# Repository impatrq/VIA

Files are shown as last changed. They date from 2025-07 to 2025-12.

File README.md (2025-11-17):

<div align="center">

# V.I.A. - IMPA TRQ

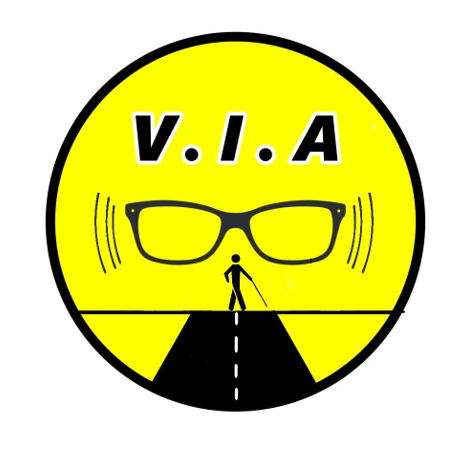
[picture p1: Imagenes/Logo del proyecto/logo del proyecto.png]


&nbsp;

| Página web | Email | Instagram |
|---|---|---|
|[VIA Web](https://linenlynx51926.github.io/VIA)|visioninteligenteasistida@gmail.com|[@vision_inteligente_asistida](https://www.instagram.com/vision_inteligente_asistida/)|

&nbsp;

</div>

## ¿Qué es VIA?

VIA es un prototipo de sistema de inspección y análisis visual para aeronaves, diseñado para optimizar procesos de verificación mediante sensores y captura de datos. Su objetivo principal es mejorar la detección temprana de fallas o anomalías a través de un análisis estructurado y automatizado.

## ¿Cómo funciona?
El sistema recibe la información proveniente de diferentes sensores y módulos de captura instalados en el equipo a inspeccionar. Mediante una secuencia guiada, VIA analiza parámetros críticos, registra lecturas y utiliza procesamiento visual para verificar el estado general.
Una vez procesados los datos, el sistema clasifica los resultados según su categoría o tipo de advertencia. Según el diagnóstico, VIA determina si el componente inspeccionado se encuentra dentro de tolerancias, si requiere seguimiento o si debe ser intervenido.
Las detecciones se organizan en cuatro categorías principales, permitiendo una interpretación clara y rápida del estado del sistema evaluado.

## ¿Quiénes somos?

Somos de la escuela tecnica IMPA, del curso 7° 2° Avionica

### GRANATA, Joaquin
* 📧 granatajoaquin@gmail.com

### RADAKOFF, Milovan
* 📧 miloradqw@gmail.com

### PAZ, Bautista
* 📧 bautistapaz504@gmail.com

### CARAM, Matias
* 📧 matias.rapero2007@gmail.com

### RAMIREZ, Selene
* 📧 seleneramirez474@gmail.com

<div align="center">

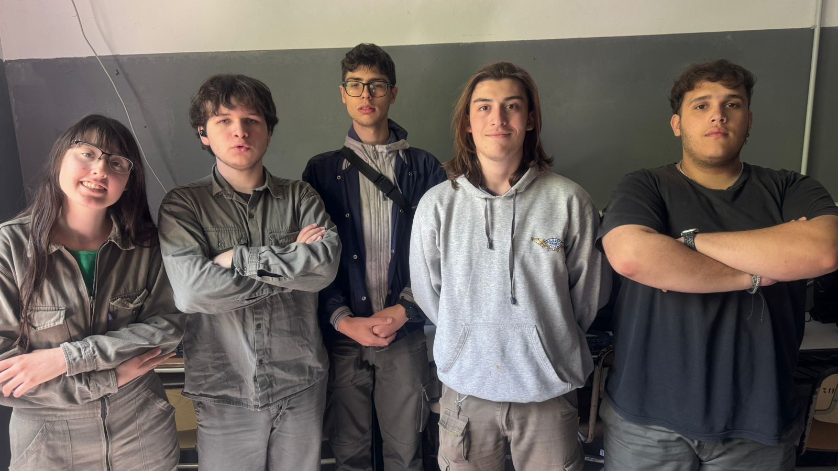
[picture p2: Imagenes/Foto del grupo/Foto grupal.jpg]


</div>

## ¿Cómo contactarnos?

* 📧 Email: visioninteligenteasistida@gmail.com

* 🌐 Página Web: https://linenlynx51926.github.io/VIA

* 🗞️ Linktr.ee: [VIA](https://linktr.ee/vision_inteligente_asistida)

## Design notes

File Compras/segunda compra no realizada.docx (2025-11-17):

11 | 1 | Sensor de proximidad | Para detectar la profundidad de los objetos en un area
12 | 1 | batería de litio | para alimetar los lentes
13 | 2 | Modulos con camaras ESP32 OV2640 de 2mp | se quemaron las 2 anteriores | https://tienda.starware.com.ar/producto/modulo-wifi-bt-camara-arduino-esp32-cam-ov2640-2mp/
14 | 1 | termocontraible | para aislar el circuito

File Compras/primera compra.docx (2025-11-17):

1 | 2 | Modulos con camaras ESP32 OV2640 de 2mp | Lo necesitamos para procesar las señales enviadas por los ecptores opticos. | https://tienda.starware.com.ar/producto/modulo-wifi-bt-camara-arduino-esp32-cam-ov2640-2mp/
2 | 1 | Placa SBC raspberry PI 5 model B 8GB RAM | Lo necesitamos para procesar, analizar y almacenar los datos que le proporcionamos. | https://tienda.starware.com.ar/producto/placa-sbc-raspberry-pi-5-model-b-8gb-ram/
3 | 1 | Sensor de proximidad DIY RCWL-0516 detector | Lo necesitamos para detectar objetos con los que se podria golpear el no vidente | https://tienda.starware.com.ar/producto/sensor-movimiento-proximidad-diy-rcwl-0516-detector-radar-doppler-microondas/
4 | 4 | Capacitores de 1μf | Para la conexión y funcionamiento del circuito de audio
5 | 4 | Capacitores ceramicos de 33μf | Para la conexión y funcionamiento del circuito de audio
6 | 4 | Resistencias de 270 ohms | Para la conexión y funcionamiento del circuito de audio
7 | 4 | Resistencias de 150 ohms | Para la conexión y funcionamiento del circuito de audio
8 | 1 | Pack de cables pin arduino macho a hembra | Es para conexiones varias
9 | 1 | Modulo amplificador audio starware PAM8403 5V | Es para transformar y amplificar la señal de audio que proviene del aparato | https://tienda.starware.com.ar/producto/modulo-amplificador-audio-starware-pam8403-5v-2ch-stereo-3w-con-volumen/
10 | 1 | Adaptador de jack a pines arduino | Lo vamos a usar para la conexión de tipo jack al circuito

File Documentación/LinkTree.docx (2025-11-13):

PARA CONOCER MAS DE ESTE GRAN PROYECTO,

¡¡TE INVITAMOS A VER NUESTROS OTROS MEDIOS!!

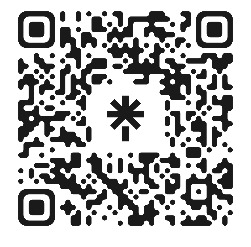
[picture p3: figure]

Visión Inteligente Artificial

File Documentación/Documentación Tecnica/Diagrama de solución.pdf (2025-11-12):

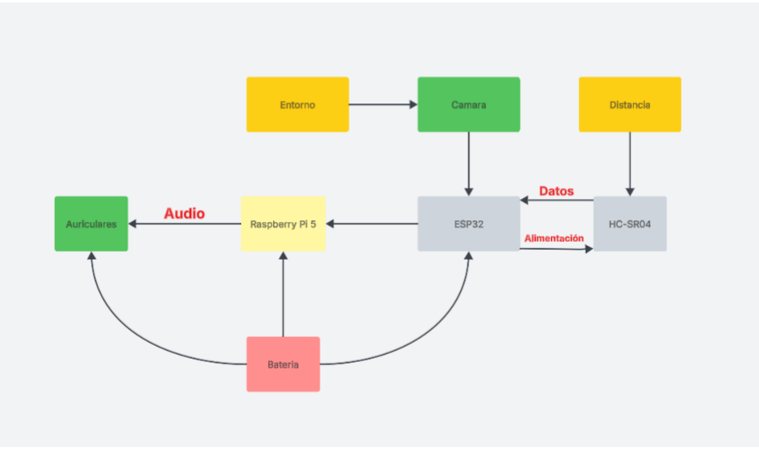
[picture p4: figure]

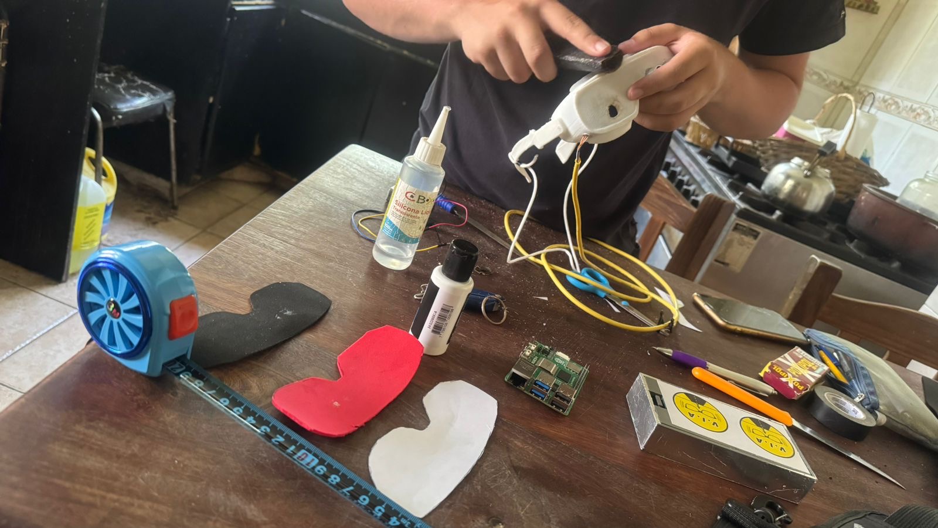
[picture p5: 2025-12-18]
Diseño de los lentes/74ddadd1-6766-4e61-b988-110f85c62abd.jpeg

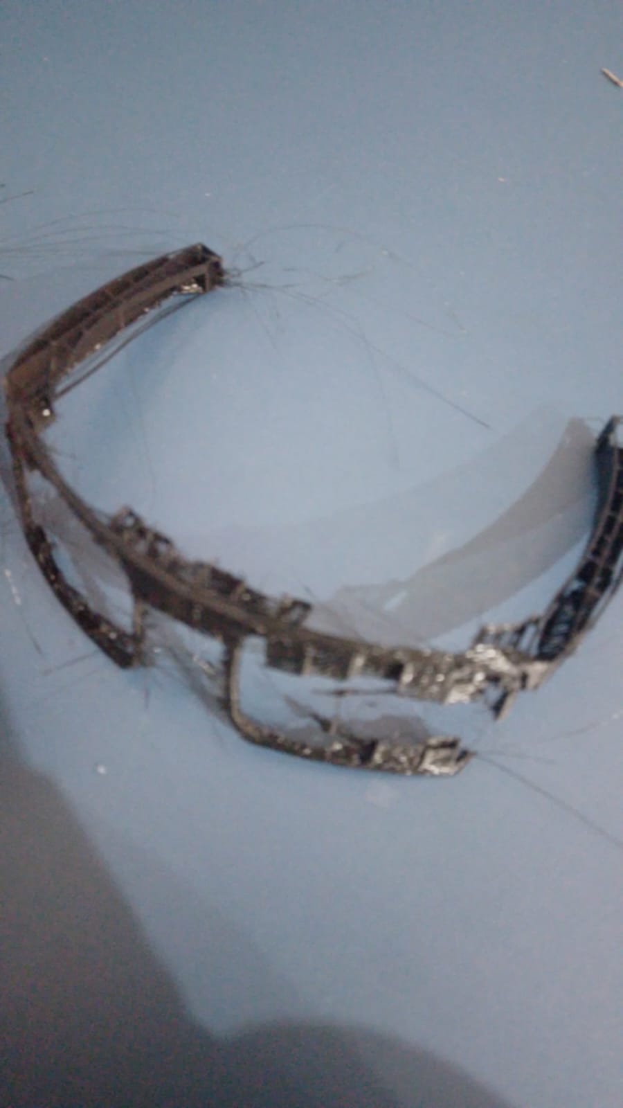
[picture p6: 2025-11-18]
Diseño de los lentes/segunda impresion de lentes.jpg

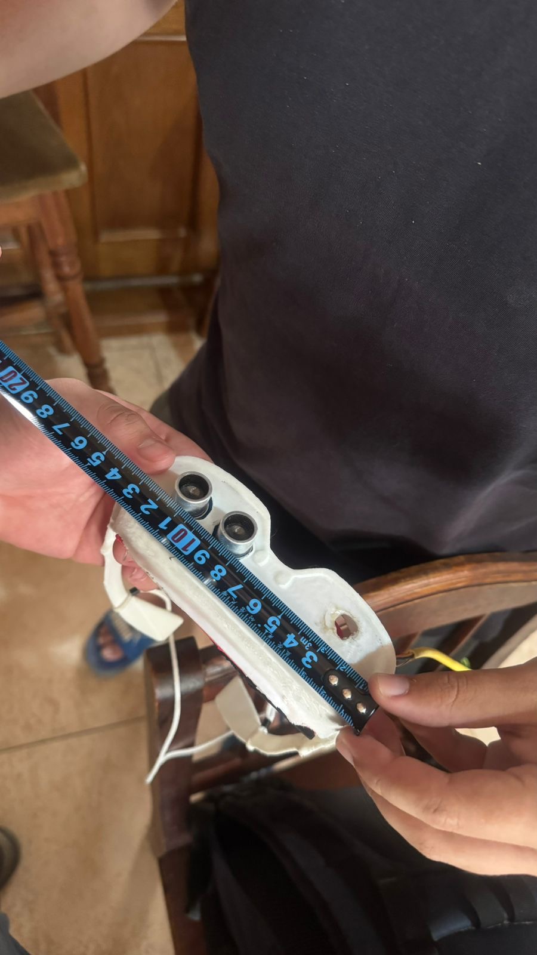
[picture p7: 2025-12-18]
Diseño de los lentes/55b00a65-91ff-49be-b2be-f18906fa94af.jpeg

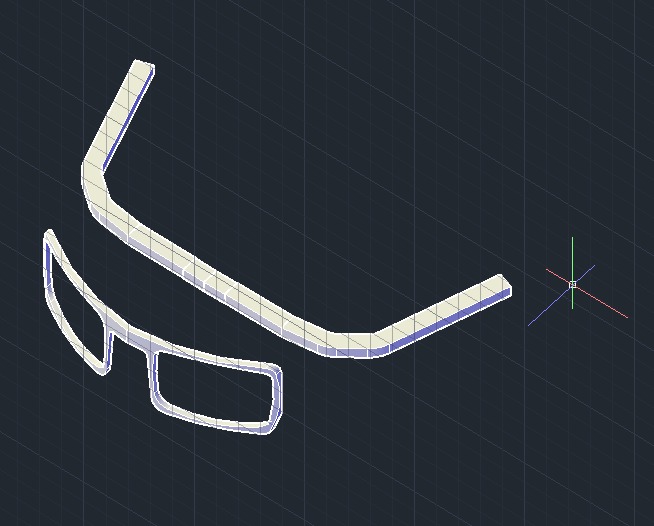
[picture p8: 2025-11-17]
Diseño de los lentes/cuarto diseño de lentes.jpg

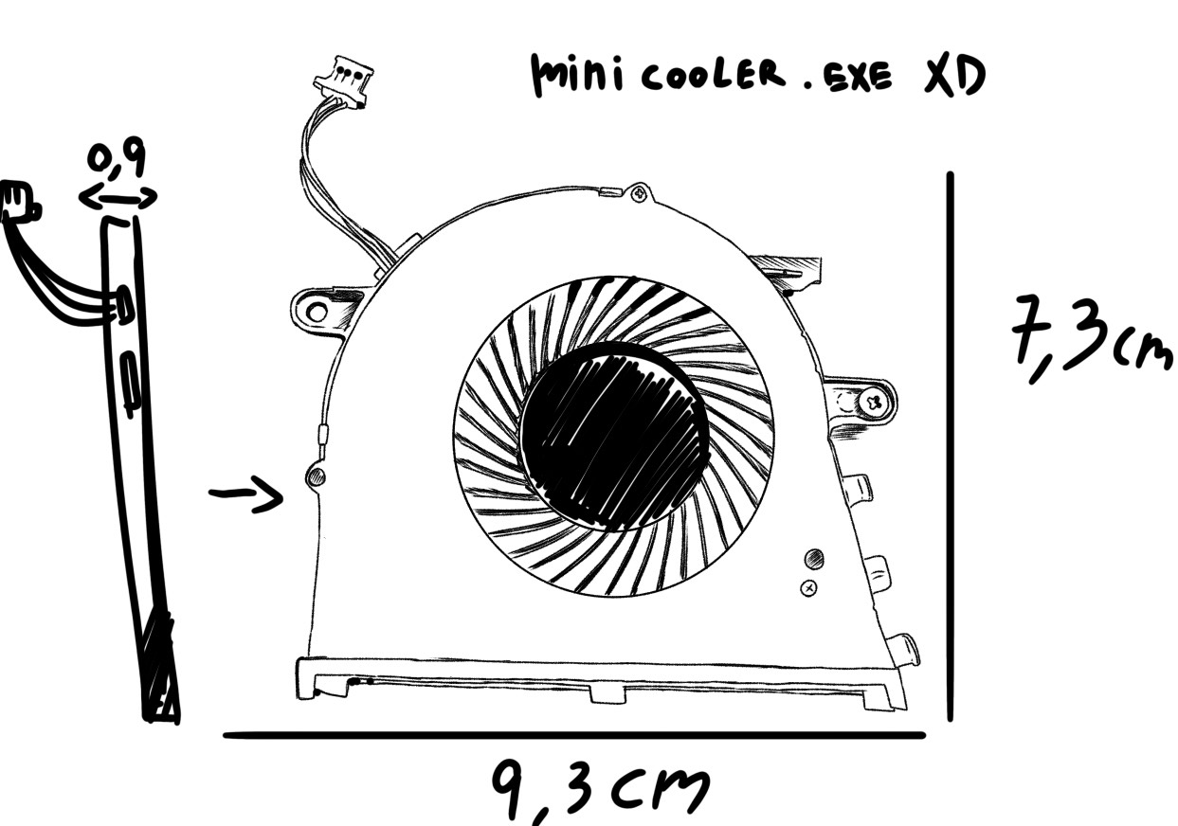
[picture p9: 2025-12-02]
Diseño de los lentes/image.png

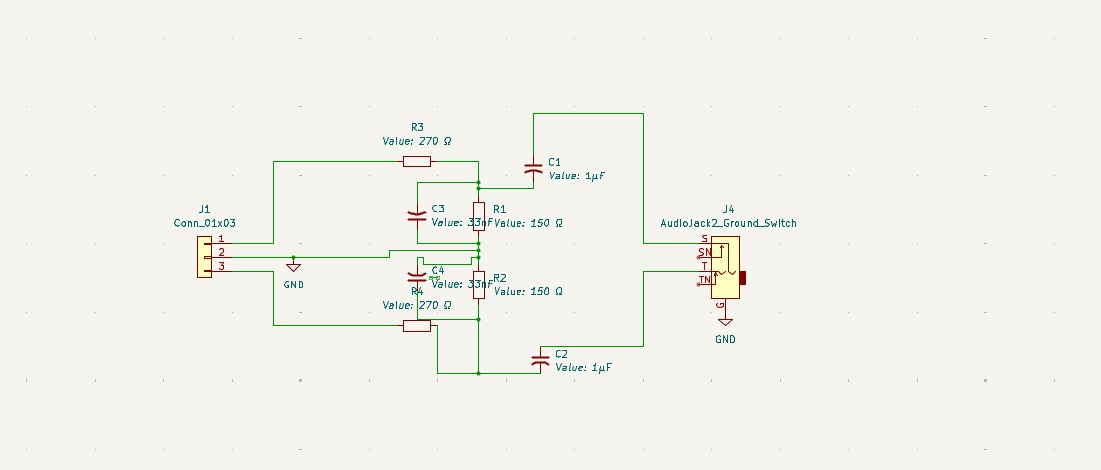
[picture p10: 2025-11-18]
circuito de audio/diseño de circuito.jpg

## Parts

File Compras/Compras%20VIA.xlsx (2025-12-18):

Planilla de compras Proyectos de 7mo Aviónica
Nombre del Proyecto |  | VIA |  | Alumnos Responsables: |  |  | AVIÓNICA
 |  |  |  | Milovan Radakoff | radakoff.milovan@gmail.com
 |  |  |  | Matias Caram | matias.rapero2007@gmail.com
Item | Cant. | Nombre del producto | Detalle del pedido | Link: | Precio por unidad | Sub Total | Fecha de solicitud | Tutores |  | Jefe de Área |  | Cooperadora
 |  |  |  |  |  |  |  | Aprobado | Fecha de aprobación | Aprobado | Fecha de aprobación | Estado | Fecha de entrega
1 | 2 | Modulos con camaras ESP32 OV2640 de 2mp | Lo necesitamos para procesar las señales enviadas por los ecptores opticos. | https://tienda.starware.com.ar/producto/modulo-wifi-bt-camara-arduino-esp32-cam-ov2640-2mp/ | $14739.00 | $29478.00 | #REF! | VERDADERO | #REF! | VERDADERO | #REF! | Presupuestando
2 | 1 | Placa SBC raspberry PI 5 model B 8GB RAM | Lo necesitamos para procesar, analizar y almacenar los datos que le proporcionamos. | https://tienda.starware.com.ar/producto/placa-sbc-raspberry-pi-5-model-b-8gb-ram/ | $125009.00 | $125009.00 | #REF! | VERDADERO | #REF! | VERDADERO | #REF! | Presupuestando
3 | 1 | Sensor de proximidad DIY RCWL-0516 detector | Lo necesitamos para detectar objetos con los que se podria golpear el no vidente | https://tienda.starware.com.ar/producto/sensor-movimiento-proximidad-diy-rcwl-0516-detector-radar-doppler-microondas/ | $5189.00 | $5189.00 | #REF! | VERDADERO | #REF! | VERDADERO | #REF! | Presupuestando
4 | 4 | Capacitores de 1μf | Para la conexión y funcionamiento del circuito de audio |  | $2618.00 | $10472.00 | #REF! | VERDADERO | #REF! | VERDADERO | #REF! | Presupuestando
5 | 4 | Capacitores ceramicos de 33μf | Para la conexión y funcionamiento del circuito de audio |  | $2618.00 | $10472.00 | #REF! | VERDADERO | #REF! | VERDADERO | #REF! | Presupuestando
6 | 4 | Resistencias de 270 ohms | Para la conexión y funcionamiento del circuito de audio |  | $1202.03 | $4808.12 | #REF! | VERDADERO | #REF! | VERDADERO | #REF! | Presupuestando
7 | 4 | Resistencias de 150 ohms | Para la conexión y funcionamiento del circuito de audio |  | $4584.00 | $18336.00 | #REF! | VERDADERO | #REF! | VERDADERO | #REF! | Presupuestando
8 | 1 | Pack de cables pin arduino macho a hembra | Es para conexiones varias |  | $3000.00 | $3000.00 | #REF! | VERDADERO | #REF! | VERDADERO | #REF! | Presupuestando
9 | 1 | Modulo amplificador audio starware PAM8403 5V | Es para transformar y amplificar la señal de audio que proviene del aparato | https://tienda.starware.com.ar/producto/modulo-amplificador-audio-starware-pam8403-5v-2ch-stereo-3w-con-volumen/ | $2279.00 | $2279.00 | #REF! | VERDADERO | #REF! | VERDADERO | #REF! | Presupuestando
10 | 1 | Adaptador de jack a pines arduino | Lo vamos a usar para la conexión de tipo jack al circuito |  | $5300.00 | $5300.00 | #REF! | VERDADERO | #REF! | VERDADERO | #REF! | Presupuestando
11 | 1 | Sensor de proximidad | Para detectar la profundidad de los objetos en un area |  | $16000.00 | $16000.00 | #REF! | VERDADERO | #REF! | VERDADERO | #REF! | Presupuestando
12 | 1 | batería de litio | para alimetar los lentes |  | $7700.00 | $7700.00 | #REF! | VERDADERO | #REF! | VERDADERO | #REF! | Presupuestando
13 | 2 | Modulos con camaras ESP32 OV2640 de 2mp | se quemaron las 2 anteriores | https://tienda.starware.com.ar/producto/modulo-wifi-bt-camara-arduino-esp32-cam-ov2640-2mp/ |  | $0.00 | #REF! |  |  |  |  | Presupuestando
14 | 1 | termocontraible | para aislar el circuito |  |  | $0.00 | #REF! |  |  |  |  | Presupuestando
15 | 1 | Auriculares óseos bluethoot | Para transmitir el mensaje al usuario sin obstruir su vía auditiva |  | $18000.00 | $18000.00 | #REF! |  |  |  |  | Presupuestando
16 |  |  |  |  |  | $0.00 |  |  |  |  |  | Presupuestando
17 |  |  |  |  |  | $0.00 |  |  |  |  |  | Presupuestando
18 |  |  |  |  |  | $0.00 |  |  |  |  |  | Presupuestando
19 |  |  |  |  |  | $0.00 |  |  |  |  |  | Presupuestando
20 |  |  |  |  |  | $0.00 |  |  |  |  |  | Presupuestando
21 |  |  |  |  |  | $0.00 |  |  |  |  |  | Presupuestando
22 |  |  |  |  |  | $0.00 |  |  |  |  |  | Presupuestando
23 |  |  |  |  |  | $0.00 |  |  |  |  |  | Presupuestando
24 |  |  |  |  |  | $0.00 |  |  |  |  |  | Presupuestando
25 |  |  |  |  |  | $0.00 |  |  |  |  |  | Presupuestando
26 |  |  |  |  |  | $0.00 |  |  |  |  |  | Presupuestando
27 |  |  |  |  |  | $0.00 |  |  |  |  |  | Presupuestando
28 |  |  |  |  |  | $0.00 |  |  |  |  |  | Presupuestando
29 |  |  |  |  |  | $0.00 |  |  |  |  |  | Presupuestando
30 |  |  |  |  |  | $0.00 |  |  |  |  |  | Presupuestando
 |  |  |  |  | Total: | $256043.12 |  | Gastado: | $0.00

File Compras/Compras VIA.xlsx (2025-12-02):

Planilla de compras Proyectos de 7mo Aviónica
Nombre del Proyecto |  | VIA |  | Alumnos Responsables: |  |  | AVIÓNICA
 |  |  |  | Milovan Radakoff | radakoff.milovan@gmail.com
 |  |  |  | Matias Caram | matias.rapero2007@gmail.com
Item | Cant. | Nombre del producto | Detalle del pedido | Link: | Precio por unidad | Sub Total | Fecha de solicitud | Tutores |  | Jefe de Área |  | Cooperadora
 |  |  |  |  |  |  |  | Aprobado | Fecha de aprobación | Aprobado | Fecha de aprobación | Estado | Fecha de entrega
1 | 2 | Modulos con camaras ESP32 OV2640 de 2mp | Lo necesitamos para procesar las señales enviadas por los ecptores opticos. | https://tienda.starware.com.ar/producto/modulo-wifi-bt-camara-arduino-esp32-cam-ov2640-2mp/ | $14739.00 | $29478.00 | 2025-06-19 14:22 | VERDADERO | 2025-06-24 14:38 | VERDADERO | 2025-07-01 16:15 | Presupuestando
2 | 1 | Placa SBC raspberry PI 5 model B 8GB RAM | Lo necesitamos para procesar, analizar y almacenar los datos que le proporcionamos. | https://tienda.starware.com.ar/producto/placa-sbc-raspberry-pi-5-model-b-8gb-ram/ | $125009.00 | $125009.00 | 2025-06-19 14:22 | VERDADERO | 2025-06-24 14:38 | VERDADERO | 2025-07-01 16:15 | Presupuestando
3 | 1 | Sensor de proximidad DIY RCWL-0516 detector | Lo necesitamos para detectar objetos con los que se podria golpear el no vidente | https://tienda.starware.com.ar/producto/sensor-movimiento-proximidad-diy-rcwl-0516-detector-radar-doppler-microondas/ | $5189.00 | $5189.00 | 2025-06-19 14:22 | VERDADERO | 2025-06-24 14:38 | VERDADERO | 2025-07-01 16:15 | Presupuestando
4 | 4 | Capacitores de 1μf | Para la conexión y funcionamiento del circuito de audio |  | $2618.00 | $10472.00 | 2025-09-09 14:00 | VERDADERO | 2025-06-24 14:38 | VERDADERO | 2025-07-01 16:15 | Presupuestando
5 | 4 | Capacitores ceramicos de 33μf | Para la conexión y funcionamiento del circuito de audio |  | $2618.00 | $10472.00 | 2025-09-09 14:00 | VERDADERO | 2025-06-24 14:38 | VERDADERO | 2025-07-01 16:15 | Presupuestando
6 | 4 | Resistencias de 270 ohms | Para la conexión y funcionamiento del circuito de audio |  | $1202.03 | $4808.12 | 2025-09-09 14:00 | VERDADERO | 2025-06-24 14:38 | VERDADERO | 2025-07-01 16:15 | Presupuestando
7 | 4 | Resistencias de 150 ohms | Para la conexión y funcionamiento del circuito de audio |  | $4584.00 | $18336.00 | 2025-09-09 14:00 | VERDADERO | 2025-06-24 14:38 | VERDADERO | 2025-07-01 16:15 | Presupuestando
8 | 1 | Pack de cables pin arduino macho a hembra | Es para conexiones varias |  | $3000.00 | $3000.00 | 2025-09-09 14:00 | VERDADERO | 2025-06-24 14:38 | VERDADERO | 2025-07-01 16:15 | Presupuestando
9 | 1 | Modulo amplificador audio starware PAM8403 5V | Es para transformar y amplificar la señal de audio que proviene del aparato | https://tienda.starware.com.ar/producto/modulo-amplificador-audio-starware-pam8403-5v-2ch-stereo-3w-con-volumen/ | $2279.00 | $2279.00 | 2025-09-09 14:00 | VERDADERO | 2025-06-24 14:38 | VERDADERO | 2025-07-01 16:15 | Presupuestando
10 | 1 | Adaptador de jack a pines arduino | Lo vamos a usar para la conexión de tipo jack al circuito |  | $5300.00 | $5300.00 | 2025-09-09 14:00 | VERDADERO | 2025-06-24 14:38 | VERDADERO | 2025-07-01 16:25 | Presupuestando
11 | 1 | Sensor de proximidad | Para detectar la profundidad de los objetos en un area |  | $16000.00 | $16000.00 | 2025-09-09 14:00 | VERDADERO | 2025-09-09 14:26 | VERDADERO | 2025-09-09 14:26 | Presupuestando
12 | 1 | batería de litio | para alimetar los lentes |  | $7700.00 | $7700.00 | 2025-10-21 10:05 | VERDADERO | 2025-09-09 14:26 | VERDADERO | 2025-09-09 14:26 | Presupuestando
13 | 2 | Modulos con camaras ESP32 OV2640 de 2mp | se quemaron las 2 anteriores | https://tienda.starware.com.ar/producto/modulo-wifi-bt-camara-arduino-esp32-cam-ov2640-2mp/ |  | $0.00 | 2025-09-16 16:21 |  |  |  |  | Presupuestando
14 | 1 | termocontraible | para aislar el circuito |  |  | $0.00 | 2025-10-21 10:05 |  |  |  |  | Presupuestando
15 | 1 | Auriculares óseos bluethoot | Para transmitir el mensaje al usuario sin obstruir su vía auditiva |  | $18000.00 | $18000.00 |  |  |  |  |  | Presupuestando
16 |  |  |  |  |  | $0.00 |  |  |  |  |  | Presupuestando
17 |  |  |  |  |  | $0.00 |  |  |  |  |  | Presupuestando
18 |  |  |  |  |  | $0.00 |  |  |  |  |  | Presupuestando
19 |  |  |  |  |  | $0.00 |  |  |  |  |  | Presupuestando
20 |  |  |  |  |  | $0.00 |  |  |  |  |  | Presupuestando
21 |  |  |  |  |  | $0.00 |  |  |  |  |  | Presupuestando
22 |  |  |  |  |  | $0.00 |  |  |  |  |  | Presupuestando
23 |  |  |  |  |  | $0.00 |  |  |  |  |  | Presupuestando
24 |  |  |  |  |  | $0.00 |  |  |  |  |  | Presupuestando
25 |  |  |  |  |  | $0.00 |  |  |  |  |  | Presupuestando
26 |  |  |  |  |  | $0.00 |  |  |  |  |  | Presupuestando
27 |  |  |  |  |  | $0.00 |  |  |  |  |  | Presupuestando
28 |  |  |  |  |  | $0.00 |  |  |  |  |  | Presupuestando
29 |  |  |  |  |  | $0.00 |  |  |  |  |  | Presupuestando
30 |  |  |  |  |  | $0.00 |  |  |  |  |  | Presupuestando
 |  |  |  |  | Total: | $256043.12 |  | Gastado: | $0.00

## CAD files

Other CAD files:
Diseño de los lentes/tercer diseño de lentes.dwg
Diseño de los lentes/segundo diseño de lentes.dwg
Diseño de los lentes/primer diseño e idea de lentes.dwg

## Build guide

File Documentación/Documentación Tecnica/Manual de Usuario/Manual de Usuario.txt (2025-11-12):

\documentclass[12pt,a4paper]{article}

% Paquetes
\usepackage[utf8]{inputenc}
\usepackage[spanish]{babel}
\usepackage{graphicx}
\usepackage{hyperref}
\usepackage{geometry}
\usepackage{titlesec}
\usepackage{xcolor}
\usepackage{fancyhdr}
\usepackage{enumitem}

\geometry{margin=2.5cm}

\pagestyle{fancy}
\fancyhf{}
\fancyhead[L]{Proyecto V.I.A.}
\fancyhead[R]{Manual de Usuario}
\fancyfoot[C]{\thepage}

\titleformat{\section}{\Large\bfseries}{\thesection.}{0.5em}{}
\titleformat{\subsection}{\large\bfseries}{\thesubsection.}{0.5em}{}

\title{\textbf{Manual de Usuario}\\Proyecto V.I.A.}
\author{Equipo de Desarrollo V.I.A.}
\date{}

\begin{document}

\maketitle
\thispagestyle{empty}
\vspace{2cm}

\begin{center}
\includegraphics[width=0.55\textwidth]{VIA-Logo.png}
\end{center}

\newpage
\tableofcontents
\newpage

\section{Introducción}
El presente documento corresponde al \textbf{Manual de Usuario} del sistema \textbf{V.I.A. (Visión Inteligente Asistida)}.  
Su propósito es ofrecer una guía clara y sencilla para poner en funcionamiento el dispositivo, sin necesidad de conocimientos avanzados en informática o programación.

El sistema \textbf{V.I.A.} fue desarrollado como una herramienta de apoyo para personas con discapacidad visual o movilidad reducida. Combina sensores ópticos, ultrasónicos y procesamiento local en una \textbf{Raspberry Pi 5} para detectar obstáculos cercanos y emitir alertas sonoras al usuario en tiempo real.

\section{Componentes principales}
\subsection{Lentes inteligentes}
Los lentes alojan los sensores del sistema:
\begin{itemize}
    \item \textbf{Cámara ESP32-CAM:} capta imágenes del entorno.
    \item \textbf{Sensor ultrasónico HC-SR04:} mide la distancia a los objetos cercanos.
\end{itemize}
Los módulos están integrados en el armazón y conectados mediante un cable a la unidad central.

\subsection{Auriculares Bluetooth}
Los auriculares son el medio por el cual el usuario recibe las alertas.  
El sistema se conecta automáticamente al encenderse, siempre que los auriculares estén emparejados una vez.

\subsection{Unidad de procesamiento (Raspberry Pi 5)}
Es el “cerebro” del sistema. Contiene el software de detección, comunicación y control.  
Al iniciar, se encarga de conectar todos los componentes y mostrar una interfaz visual en pantalla o en otro dispositivo.

\section{Requisitos previos}
Antes de usar el sistema, asegúrese de:
\begin{itemize}
    \item Contar con todos los módulos correctamente conectados (lentes, cámara, sensor y auriculares).
    \item Tener una fuente de alimentación estable (5V / 3A).
    \item Haber realizado el emparejamiento inicial de los auriculares Bluetooth (solo la primera vez).
\end{itemize}

\section{Encendido y funcionamiento}
\subsection{Inicio automático}
Al conectar la Raspberry Pi:
\begin{enumerate}
    \item Se inicia automáticamente el sistema V.I.A.  
    \item En pantalla (o en un dispositivo conectado) aparecerá la interfaz principal con opciones como:
    \begin{itemize}
        \item \textbf{Iniciar detección}
        \item \textbf{Ver cámara}
        \item \textbf{Estado del sistema}
        \item \textbf{Apagar o reiniciar}
    \end{itemize}
    \item Los auriculares emitirán un sonido de confirmación al estar listos.
\end{enumerate}

\subsection{Modo detección}
Al presionar el botón \textbf{“Iniciar detección”} en la interfaz:
\begin{itemize}
    \item El sistema comienza a analizar el entorno con la cámara y el sensor ultrasónico.  
    \item Si se detecta un obstáculo cercano, los auriculares emiten un tono o mensaje de advertencia.  
    \item El nivel de alerta varía según la distancia detectada.
\end{itemize}

\subsection{Modo monitoreo (opcional)}
Si el sistema está conectado a una pantalla o red local, se puede acceder desde un navegador en:
\begin{center}
\textbf{http://via.local}
\end{center}
Allí es posible visualizar las imágenes y el estado de los sensores en tiempo real.

\section{Solución de problemas}
\begin{itemize}
    \item \textbf{No se escuchan las alertas:}  
    Verifique que los auriculares estén encendidos y dentro del alcance. Si es necesario, repita el emparejamiento desde la interfaz.

    \item \textbf{El sistema no inicia:}  
    Compruebe la fuente de alimentación y los cables de conexión. Si la pantalla muestra un error, reinicie el dispositivo.

    \item \textbf{El sensor no responde:}  
    Revise que el sensor ultrasónico esté limpio y firmemente conectado. Evite ambientes húmedos o con polvo.

    \item \textbf{La cámara no muestra imagen:}  
    Verifique que la cámara esté correctamente orientada y que no haya objetos cubriendo la lente.
\end{itemize}

\section{Mantenimiento básico}
\begin{itemize}
    \item Limpie la cámara y el sensor con un paño seco.  
    \item Guarde los lentes en un lugar seco y seguro.  
    \item Actualice el software del sistema cuando la interfaz lo indique.  
    \item No conecte ni desconecte módulos con el sistema encendido.
\end{itemize}

\section{Seguridad}
\begin{itemize}
    \item No exponga el sistema al agua o altas temperaturas.  
    \item Mantenga los cables y conexiones en buen estado.  
    \item Utilice solo cargadores certificados de 5V / 3A.  
    \item No manipule la Raspberry Pi sin desconectarla previamente.
\end{itemize}

\section{Datos técnicos}
\begin{itemize}
    \item \textbf{Procesador:} Raspberry Pi 5 (Quad-Core Cortex-A76)
    \item \textbf{Cámara:} ESP32-CAM OV2640
    \item \textbf{Sensor:} HC-SR04
    \item \textbf{Conectividad:} WiFi 2.4 GHz, Bluetooth 5.0
    \item \textbf{Alimentación:} 5V / 3A
    \item \textbf{Software:} Python 3.11, OpenCV, Flask
\end{itemize}

\section{Soporte técnico}
En caso de inconvenientes, comuníquese con el equipo del Proyecto V.I.A. mediante los canales institucionales o correo electrónico del grupo de desarrollo.

\vfill
\begin{center}
\textit{“VIA – Con nosotros, cada paso es un paso seguro.”}
\end{center}

\end{document}

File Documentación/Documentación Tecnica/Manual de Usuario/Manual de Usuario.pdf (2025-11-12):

# Manual de Usuario

Proyecto V.I.A.

Equipo de Desarrollo V.I.A.

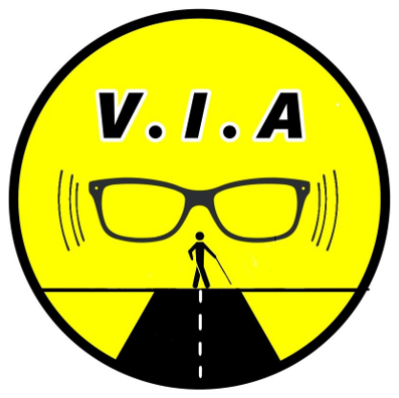
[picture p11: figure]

Proyecto V.I.A. | Manual de Usuario

## Índice

1. Introducción | 3
2. Componentes principales | 3
3. Requisitos previos | 3
4. Encendido y funcionamiento | 4
5. Solución de problemas | 4
6. Mantenimiento básico | 5
7. Seguridad | 5
8. Datos técnicos | 5
9. Soporte técnico | 5

## 1. Introducción

El presente documento corresponde al Manual de Usuario del sistema V.I.A. (Visión Inteligente Asistida). Su propósito es ofrecer una guía clara y sencilla para poner en funcionamiento el dispositivo, sin necesidad de conocimientos avanzados en informática o programación.
El sistema V.I.A. fue desarrollado como una herramienta de apoyo para personas con discapacidad visual o movilidad reducida. Combina sensores ópticos, ultrasónicos y procesamiento local en una Raspberry Pi 5 para detectar obstáculos cercanos y emitir alertas sonoras al usuario en tiempo real.

## 2. Componentes principales

### 2.1. Lentes inteligentes

Los lentes alojan los sensores del sistema:

Cámara ESP32-CAM: capta imágenes del entorno.

Sensor ultrasónico HC-SR04: mide la distancia a los objetos cercanos.

Los módulos están integrados en el armazón y conectados mediante un cable a la unidad central.

### 2.2. Auriculares Bluetooth

Los auriculares son el medio por el cual el usuario recibe las alertas. El sistema se conecta automáticamente al encenderse, siempre que los auriculares estén emparejados una vez.

### 2.3. Unidad de procesamiento (Raspberry Pi 5)

Es el “cerebro” del sistema. Contiene el software de detección, comunicación y control. Al iniciar, se encarga de conectar todos los componentes y mostrar una interfaz visual en pantalla o en otro dispositivo.

## 3. Requisitos previos

Antes de usar el sistema, asegúrese de:

Contar con todos los módulos correctamente conectados (lentes, cámara, sensor y auriculares).

Tener una fuente de alimentación estable (5V / 3A).

Haber realizado el emparejamiento inicial de los auriculares Bluetooth (solo la primera vez).

## 4. Encendido y funcionamiento

### 4.1. Inicio automático

Al conectar la Raspberry Pi:

1. Se inicia automáticamente el sistema V.I.A.
2. En pantalla (o en un dispositivo conectado) aparecerá la interfaz principal con opciones como:

Iniciar detección

Ver cámara

Estado del sistema

Apagar o reiniciar

3. Los auriculares emitirán un sonido de confirmación al estar listos.

### 4.2. Modo detección

Al presionar el botón “Iniciar detección” en la interfaz:

El sistema comienza a analizar el entorno con la cámara y el sensor ultrasónico.

Si se detecta un obstáculo cercano, los auriculares emiten un tono o mensaje de advertencia.

El nivel de alerta varía según la distancia detectada.

### 4.3. Modo monitoreo (opcional)

Si el sistema está conectado a una pantalla o red local, se puede acceder desde un navegador en:

http://via.local

Allí es posible visualizar las imágenes y el estado de los sensores en tiempo real.

## 5. Solución de problemas

No se escuchan las alertas: Verifique que los auriculares estén encendidos y dentro del alcance. Si es necesario, repita el emparejamiento desde la interfaz.

El sistema no inicia: Compruebe la fuente de alimentación y los cables de conexión. Si la pantalla muestra un error, reinicie el dispositivo.

El sensor no responde: Revise que el sensor ultrasónico esté limpio y firmemente conectado. Evite ambientes húmedos o con polvo.

La cámara no muestra imagen: Verifique que la cámara esté correctamente orientada y que no haya objetos cubriendo la lente.

## 6. Mantenimiento básico

Limpie la cámara y el sensor con un paño seco.

Guarde los lentes en un lugar seco y seguro.

Actualice el software del sistema cuando la interfaz lo indique.

No conecte ni desconecte módulos con el sistema encendido.

## 7. Seguridad

No exponga el sistema al agua o altas temperaturas.

Mantenga los cables y conexiones en buen estado.

Utilice solo cargadores certificados de 5V / 3A.

No manipule la Raspberry Pi sin desconectarla previamente.

## 8. Datos técnicos

Procesador: Raspberry Pi 5 (Quad-Core Cortex-A76)

Cámara: ESP32-CAM OV2640

Sensor: HC-SR04

Conectividad: WiFi 2.4 GHz, Bluetooth 5.0

Alimentación: 5V / 3A

Software: Python 3.11, OpenCV, Flask

## 9. Soporte técnico

En caso de inconvenientes, comuníquese con el equipo del Proyecto V.I.A. mediante los canales institucionales o correo electrónico del grupo de desarrollo.

“VIA – Con nosotros, cada paso es un paso seguro.”

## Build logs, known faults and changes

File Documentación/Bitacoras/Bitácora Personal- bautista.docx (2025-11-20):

# Bitácora Personal

Bautista Paz 7° 2° aviónica com B proyecto V.I.A

# 16/4 (miercoles 16 de abril)

Comienzo a hacer el logo del proyecto V.I.A

18/4 (viernes 18 de abril)

Después de haber terminado con el logo, empecé un curso de programación para así poder practicar y mejorar.

23/4 (miércoles 23 de abril)

Después de ir viendo el curso y de que me sugirieran ir practicando, pensé en hacer un bot de respuesta para ir poniendo a prueba si aprendí algo.

29/4 (martes 29 de abril)

Después de ver algunos cursos y tutoriales faltaba saber como iba a programar todo y primero pensé hacerlo en visual studio code y descargando por así decirlo el lenguaje de phyton para poder usarlo en VSC. Y de ahí empezar a practicar para programa un chatbot simple.

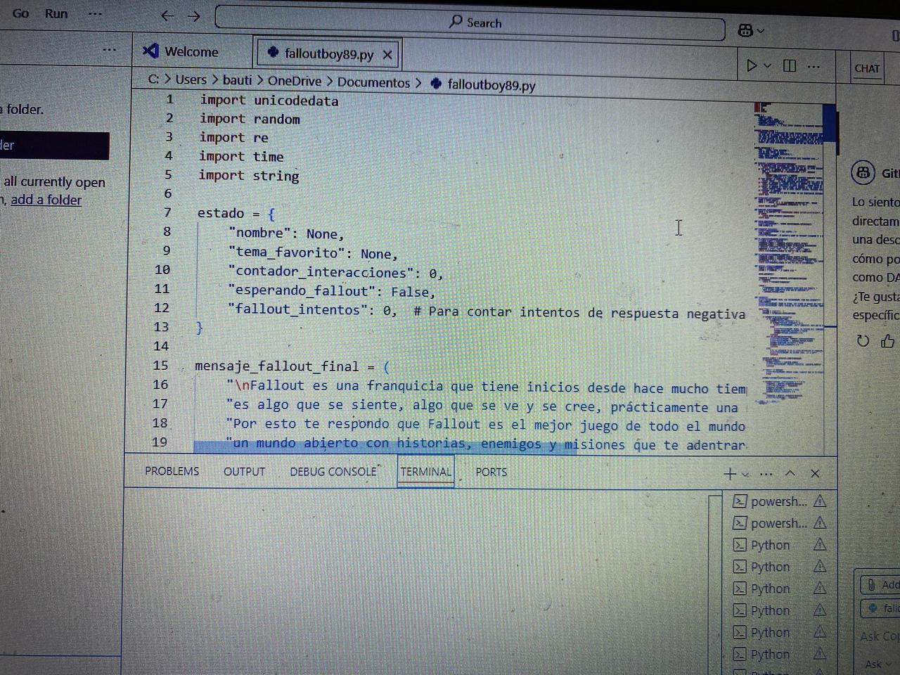
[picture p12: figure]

(ahora que lo pienso tuve que haber sacado más fotos del comienzo para que se vea mejor el progreso)

6/5 (martes 5 de mayo)

Después de ver el curso de programación y ya haber avanzado mas con el chatbot siendo que ahora aparte de hablar de mi temática favorita también hice que pudiera cambiar su forma de ser y hablar conforme la persona que habla para que así no sea repetitivo en cuanto al tema que hablará y como lo hará

7/5 (miércoles 7 de mayo)

Al dia siguiente pensé en dejarlo por ahora para seguirlo mas a futuro y pensar hacer un bot de respuesta que responda todo en base a datos ya sea de Wikipedia sin necesidad de depender de una red wi fi y así sea una biblioteca andante sin necesidad de pesar hasta 1T de espacio. Ahora lo que tocaba era programar el sensor de proximidad.

13/5 (martes 13 de mayo)

Empezando a programar las bases del sensor de proximidad pensando en un sistema que ayude a las personas que padezcan de ceguera el poder moverse por las calles sin problemas y para esto terminé simulando en wokwi.

16/5 (viernes 16 de mayo)

Hubo problemas al tratar de simular el sensor de proximidad con wokwi, asi que se cambió a arduino ya que no había dificultades al programar y simular (pd: me recomendaron hacerlo en tinkercad como alternativa)

#define TRIG_PIN 9

#define ECHO_PIN 8

#define BUZZER_A 7

#define BUZZER_B 6

#define BUZZER_C 5

void setup() {

Serial.begin(9600);

pinMode(TRIG_PIN, OUTPUT);

pinMode(ECHO_PIN, INPUT);

pinMode(BUZZER_A, OUTPUT);

pinMode(BUZZER_B, OUTPUT);

pinMode(BUZZER_C, OUTPUT);

}

void loop() {

digitalWrite(TRIG_PIN, LOW);

delayMicroseconds(2);

digitalWrite(TRIG_PIN, HIGH);

delayMicroseconds(10);

digitalWrite(TRIG_PIN, LOW);

long duracion = pulseIn(ECHO_PIN, HIGH);

float distancia = duracion * 0.0343 / 2;

// Apaga todos los buzzers antes de activar el correcto

digitalWrite(BUZZER_A, LOW);

digitalWrite(BUZZER_B, LOW);

digitalWrite(BUZZER_C, LOW);

if (distancia <= 200) {

Serial.println("Objeto adelante");

digitalWrite(BUZZER_A, HIGH);

}

else if (distancia > 200 && distancia <= 350) {

Serial.println("Objeto acercándose");

digitalWrite(BUZZER_B, HIGH);

}

else {

Serial.println("Camino despejado");

digitalWrite(BUZZER_C, HIGH);

}

delay(1000);

28/5 (miércoles 28 de mayo)

Se tuvo la reunión con la ASAC una asociación que ayuda a las personas con ceguera y por eso mismo gracias a ellos se aprendio mejor y se recibió mayor información de estos.

Martes 3 de junio

Después de la compra de algunos componentes me puse a instalar las aplicaciones para poder así programár todo para los sensores de movimiento. Para esto busque primero formas fáciles de probarlo y encontré termius, una aplicación que me ayudaba a probar el código de los sensores de proximidad sin problema.

Miércoles 4 de junio

Como no había buzzers en su momento tuve que usar leds de colores para simular las distancias (rojo = objeto cerca; verde = objeto lejos; amarillo objeto aproximándose). Y esto llevaba a que tenga que cambiar el código a uno de leds.

#define TRIG_PIN 9

#define ECHO_PIN 8

#define BUZZER_A 7

#define BUZZER_B 6

#define BUZZER_C 5

void setup() {

Serial.begin(9600);

pinMode(TRIG_PIN, OUTPUT);

pinMode(ECHO_PIN, INPUT);

pinMode(BUZZER_A, OUTPUT);

pinMode(BUZZER_B, OUTPUT);

pinMode(BUZZER_C, OUTPUT);

}

void loop() {

digitalWrite(TRIG_PIN, LOW);

delayMicroseconds(2);

digitalWrite(TRIG_PIN, HIGH);

delayMicroseconds(10);

digitalWrite(TRIG_PIN, LOW);

long duracion = pulseIn(ECHO_PIN, HIGH, 30000); // timeout opcional de 30 ms

if (duracion == 0) {

Serial.println("Sin lectura (fuera del rango)");

digitalWrite(BUZZER_A, LOW);

digitalWrite(BUZZER_B, LOW);

digitalWrite(BUZZER_C, LOW);

} else {

float distancia = duracion * 0.0343 / 2;

Serial.print("Distancia: ");

Serial.print(distancia);

Serial.println(" cm");

digitalWrite(BUZZER_A, LOW);

digitalWrite(BUZZER_B, LOW);

digitalWrite(BUZZER_C, LOW);

if (distancia <= 200) {

Serial.println("Objeto adelante");

digitalWrite(BUZZER_A, HIGH);

} else if (distancia <= 350) {

Serial.println("Objeto acercándose");

digitalWrite(BUZZER_B, HIGH);

} else {

Serial.println("Camino despejado");

digitalWrite(BUZZER_C, HIGH);

}

}

delay(1000);

}

Martes 10 de junio.

Para usar termius me di cuenta que primero necesito la IP de la raspberry pi 5, asi que para eso tuve que empezar a instalar algunas cosas como raspberry pi imager, poner una SD de 16 gb (elección propia ya que el minimo son 8gb) y de ahí formatearla para ponerle el sistema operativo de 64 bits. Pero no pude empezarlo ya que hacia falta de 2 cosas, monitor (junto a teclado y mouse pero eso no había problema) y un adaptador HDMI a micro HDMI.

Miércoles 11 de junio.

Tristemente aun carecíamos de adaptador asi pero ya teníamos a alguien que nos preste monitor.asi que decidí ver si si no había errores con el código de los sensores de proximidad.

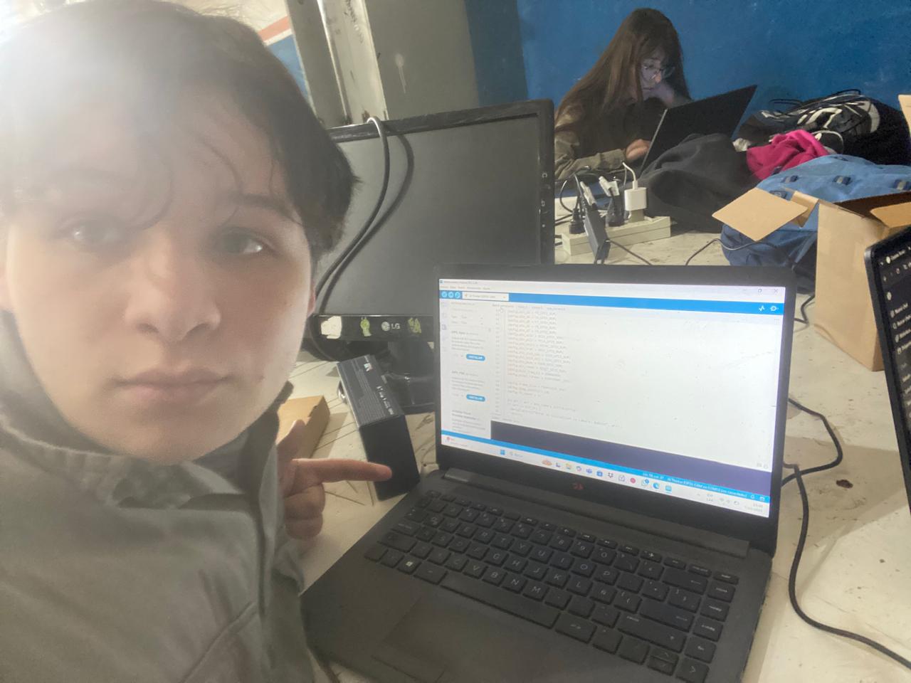
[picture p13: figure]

Martes 17 de junio.

Luego de unos dias aun faltaba para conseguir un adaptador propio así que haciendo lo que me dijo granata (pedirle el adaptador a carla) fui y al final logré conectar la rapsberry a la pc solo hacia falta el sistema operativo. El cual un compañero ya se escargaba de hacerlo.

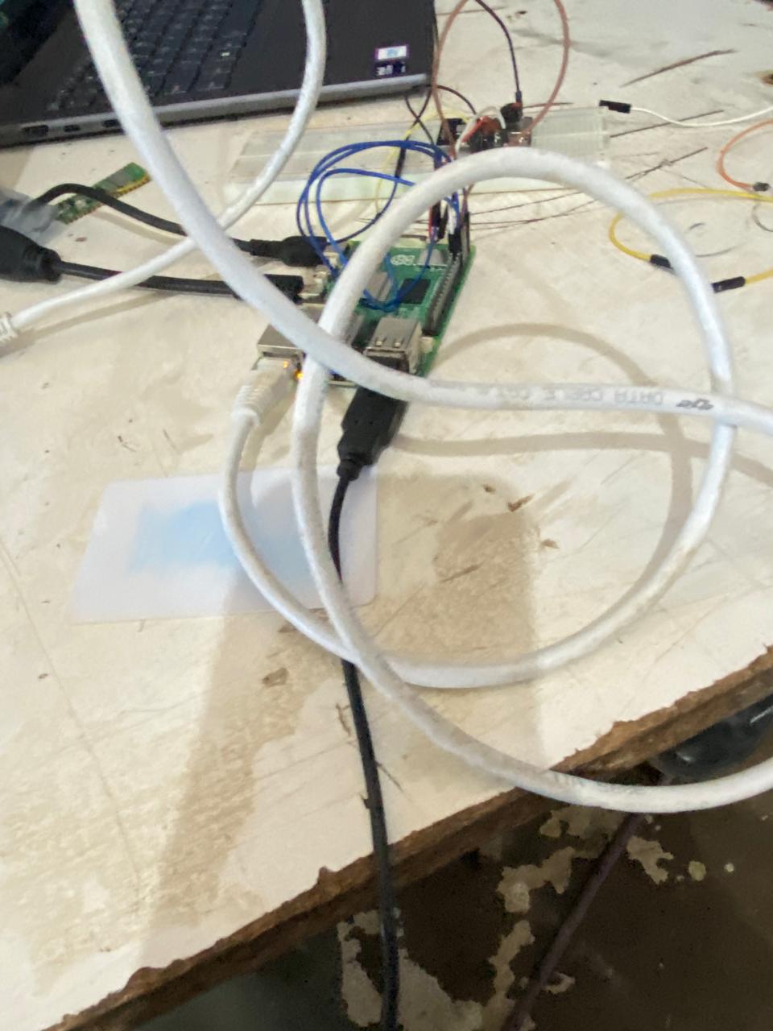
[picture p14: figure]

Martes 24 de junio.

Luego de unos contratiempos y de esperar al final terminé haciendo el sistema operativo para la raspberry pi 5 con raspberry pi imager y una micro sd de 16 gb (gracias de paso a medina por darnos la opción). Luego de evitarnos usar mucho tiempo en el S.O y programarla para que se conecte a redes wifi, continué con lo que viene siendo el código de los sensores de proximidad, cosa que al principio hubo unos inconvenientes así que tuve que mejorar el código para que sea mas preciso a la hora de avisar de objetos cercanos.

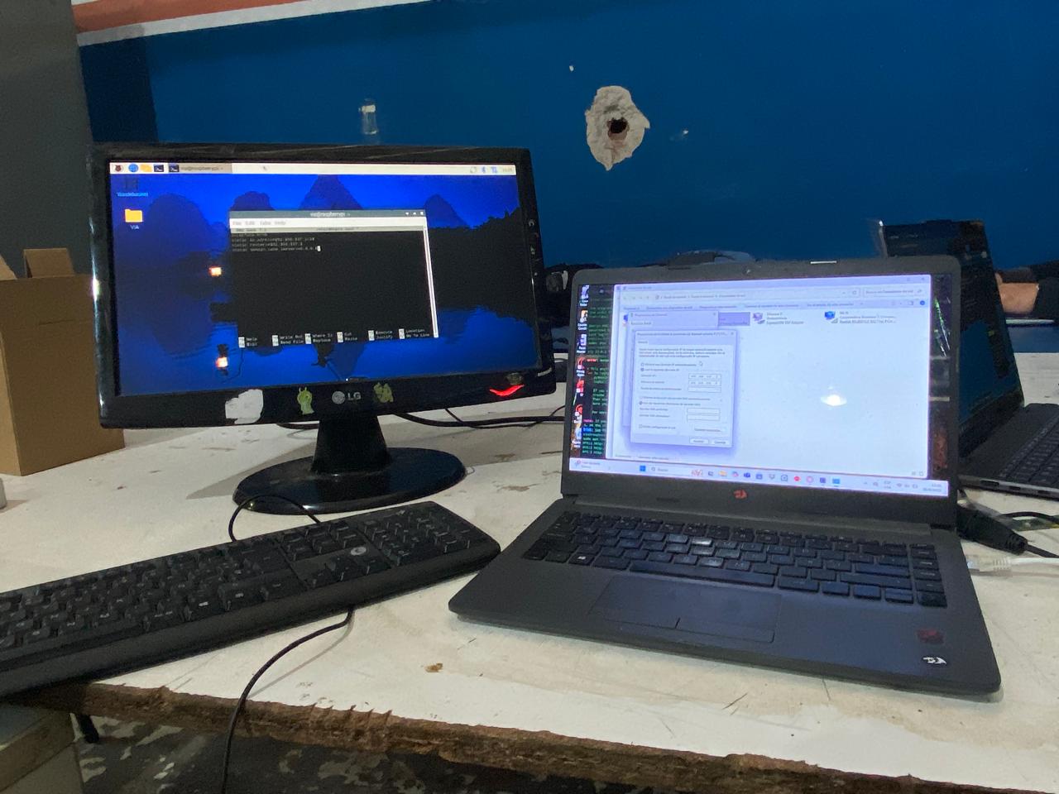
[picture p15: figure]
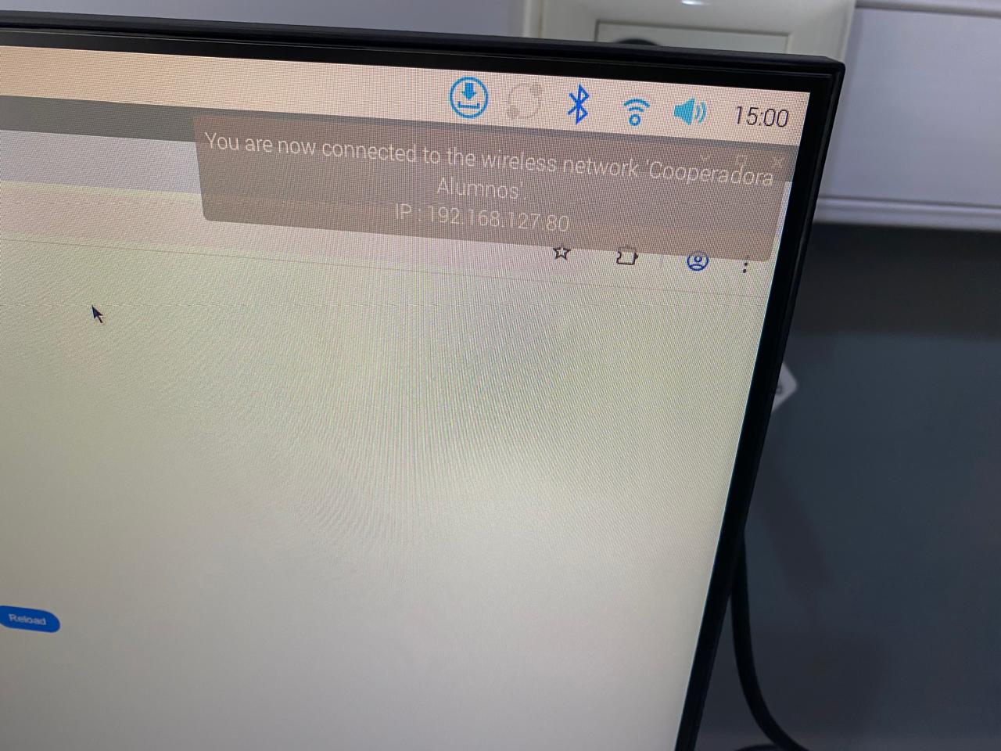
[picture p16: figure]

Martes 1 de julio.

Luego de poder mejorar la precisión del sensor ultrasónico (al final el problema era el sensor ya que el que teníamos era de corta distancia) y usar uno de más alcance logré hacer definitivamente que funcione con precisión el sensor de proximidad.

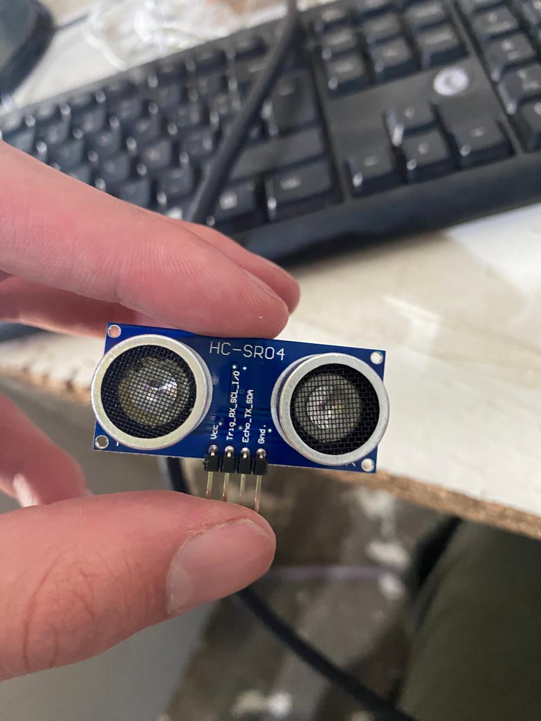
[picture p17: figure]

(sensor usado para el código)

viernes 4 de julio.

Para este momento ya empezamos a probar hacer entre granata y yo el código de la cámara para probarla, lo primero sería sacar fotos cada 1 segundo, de esta forma podría server básicamente para probar la velocidad en la que toma fotos y de paso ver que funcione. Para esto usé termius y empecé con algunos códigos. Use la IP de la raspberry para empezar a programar en termius. Y ya que no teníamos un conversor TTL decidimos hacerlo usando una micro esp que servía para poder conectar la cámara a la rapsberry y de ahí poder hacer que funcione.

Martes 8 de julio.

Tuvimos inconvenientes tratando de hacer que la raspberry detecte la esp32 cam, hicimos de todo: hacer reboot, conectar de nuevo los pines de la esp32 cam a la micro esp a la raspberry pi 5 e incluso ver en la terminar de termius para ver si podía detectar a la esp32 nada funcionó.

Viernes 11 de julio.

Este dia decidí ver errores que haya tenido, como la IP (que cuando conecto la rasp 5 cambiaba ) o ver si no era un problema de programación, y al final con ayuda de granata decidimos que era buena idea hacerlo en arduino IDE ya que usaba C++ y aparte podes especificar que tipo de esp usas.

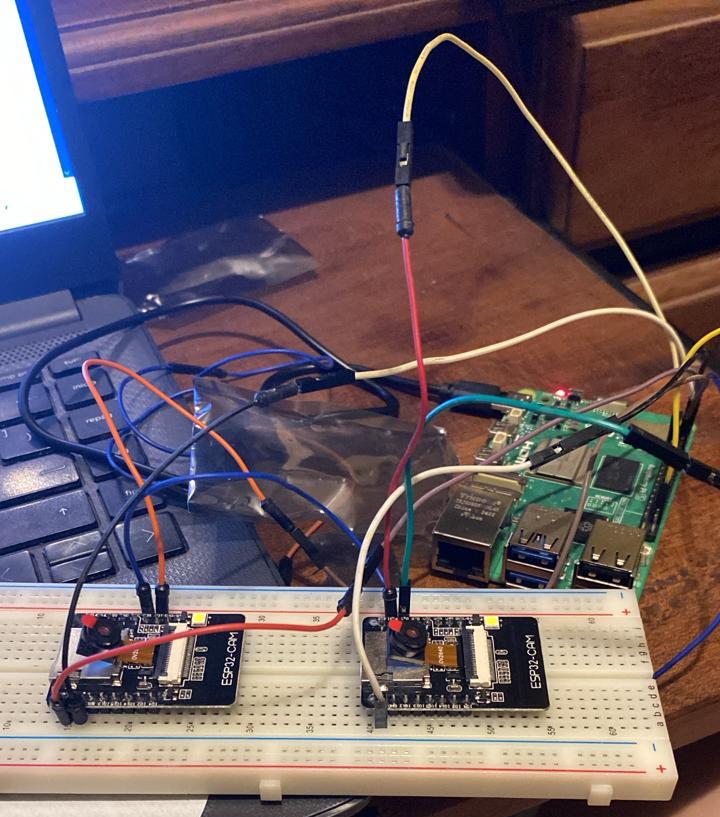
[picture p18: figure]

Martes 15 de julio

Justo este dia hubo tormenta y se inundó bastante, encima un árbol viejo calló y quien tuvo que sacarlo con una sierra y fuerza fui yo porque nadie lo sacaba B).

Viernes 15 de julio.

La esp32 cam que teníamos (1 de las 2) no funcionaba así que usamos la de repuesto y ahí empezamos con la codificación y los problemas y errores como librerías, al final empezamos a ver que podría faltarle y vimos que los pines de la cámara también estaban mal así que lo arreglamos. El único problema ahora era el espacio que ocupaba el código era muy grande.

Miércoles 6 de agosto

Granata al final terminó simplificando mas el código para que funcione en la esp 32 ya que esta no puede expandir su memoria a menos que compres una nueva. Y después de ahí funcionó bastante bien.

Martes 12 de agosto.

Apartir de aquí empezamos a probar la cámara y ver de que no haya errores con la misma

Viernes 15 de agosto

Mejorando el código del sensor de proximidad para que aunque tenga menor alcance, la lectura sea mas rápida.

Martes 19 de agosto

Viendo que cosas a mejorar y si hay errores.

Opciones: comodidad de los componentes en los lentes y ubicación del cableado.

Viernes 22 de agosto

Me puse a soldar cables para conectar del conversor serie a TTL, usando cables largos de ethernet y soldarle jumpers hembras para conectarlos y que la información y video de la cámara se mande a la raspberry pi 5 con mayor alcance y no moleste.

Miércoles 27 de agosto.

Debriefing del equipo de que ya tenemos hecho y cosas a terminar y ensamblar.

Miércoles 3 de septiembre

Faltaría ensamblar los lentes pero dentro de todo ya está terminado lo de las cámaras y el sensor de proximidad

Martes 9 de septiembre

Hoy estuvimos viendo en que ayudar para terminar el proyecto con anticipación.

Martes 16 de septiembre

Voy a hacer que la cámara detecte objetos ya sea perros, humanos, etc. Por ahora recién empezando

Miércoles 17 de septiembre

Ya descargué un modelo pre-entrenado y librerías para que funcione.

Miércoles 24 de septiembre

Hubo un problema y es que la librería está en ingles así que por ahora habrá que buscar una que esté en español.

Martes 30 de septiembre.

Como no llegue a encontrar una librería en español y ya tenia que comenzar con el detector de objetos para la raspberry entonces lo dejé así.

Miércoles 1 de octubre.

Hoy trabajé con el detector de objetos de la raspberry. V3.0

Martes 7 de octubre

Hoy logré mejorar el detector de objetos (V4.1.2)

Miércoles 8 de octubre

Ya terminado todo eso me puse a hacer el diagrama de los lentes y sus partes como los componentes que lleva.

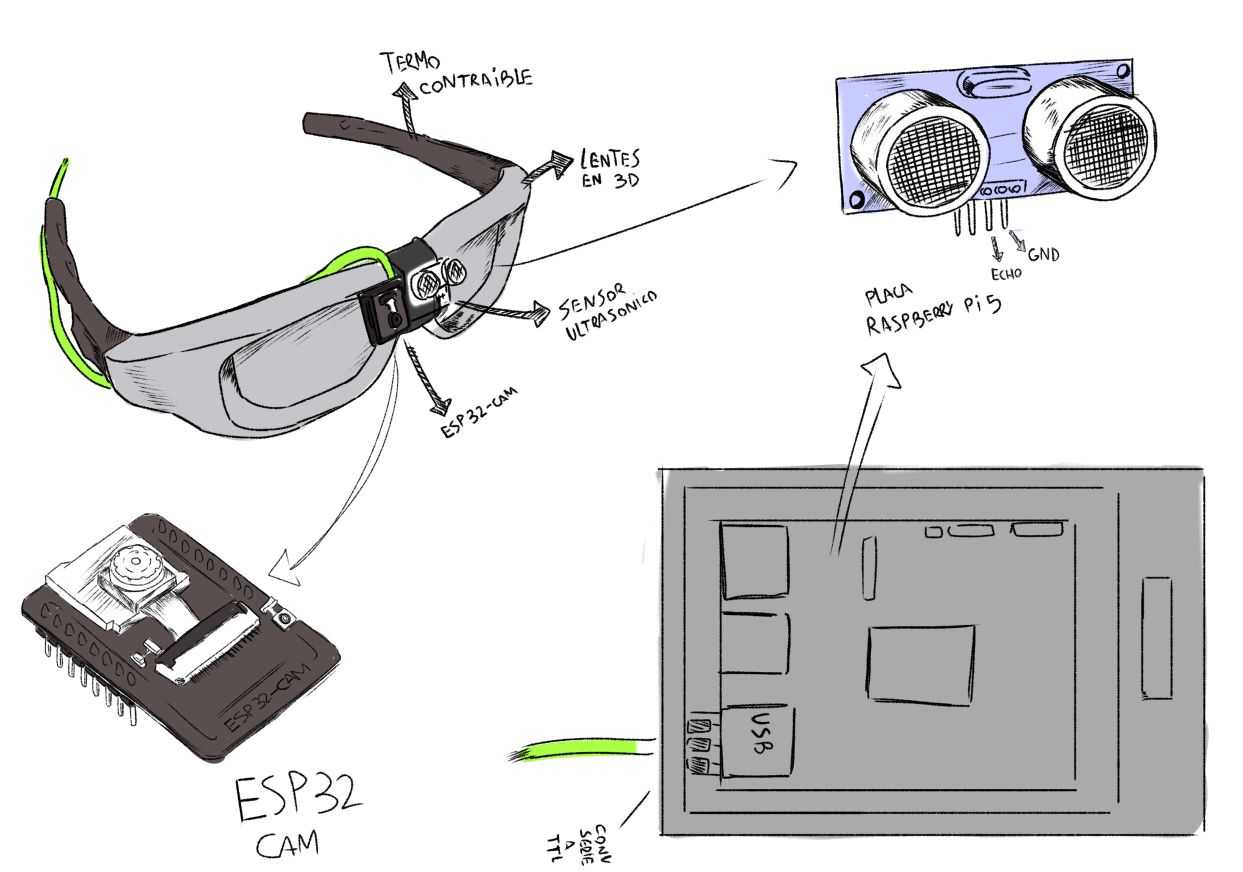
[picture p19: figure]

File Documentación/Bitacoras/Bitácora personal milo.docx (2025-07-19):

Bitácora personal

Milovan Radakoff – 7° 2° Aviónica Comisión A – Proyecto: VIA

11/4 (viernes 11 de abril)

Empiezo a programar la red

E intento hacerlo en vs code, pero no me es posible

18/4 (viernes 18 de abril)

Continuo con la programación

22/4 (martes 22 de abril)

Luego de definir nuestros puestos, comencé una primera prueba de la página

23/4 (miércoles 23 de abril)

Tengo una primera instancia de la página

29/4 (martes 29 de abril)

Investigo como hostearlo desde github

Y hago un primer lanzamiento de prueba

6/5 (martes 5 de mayo)

Continuo con la programación de la red y recopilo información para alimentarla

9/5 (viernes 9 de mayo)

Nos comunicamos con una organización de ayuda a la gente no vidente para acordar una reunión. Esto con el fin de obtener su apoyo.

14/5 (miércoles 14 de mayo)

Hago las primeras pruebas de la red, aunque precaria, consigue una buena expectativa con imágenes de internet

30/5 (viernes 30 de mayo)

Realizamos una reunión con la directora de la organización ASAC, una organización que ayuda a las personas ciegas y de visión reducida. La razón de la reunión fue la de recopilar y reunir información sobre algunos de los problemas que la gente debe afrontar en su día a día para poder implementarla en nuestra red neuronal, como posibles obstaculos. Además, acordamos vernos de nuevo para que nos den su feedback de futuras actualizaciones o avances.

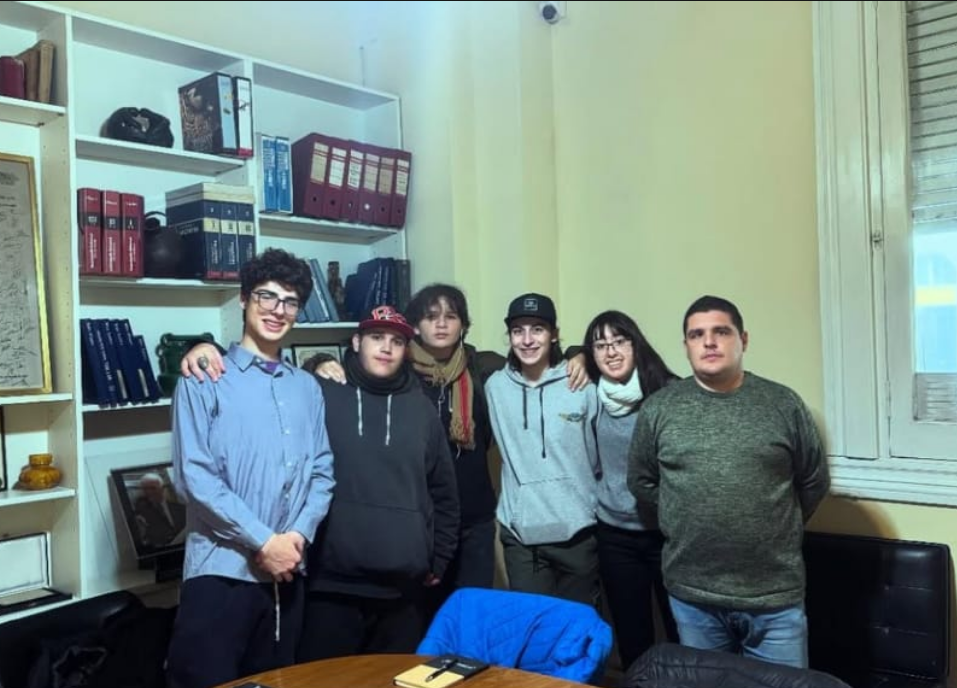
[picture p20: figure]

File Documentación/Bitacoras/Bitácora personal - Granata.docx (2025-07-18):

Bitácora personal

Granata Joaquín – 7° 2° Aviónica Comisión A – Proyecto: VIA

11/4 (viernes 11 de abril)

Empiezo un modelo del proyecto en Blender.

Empiezo a ver tutoriales para aprender Blender.

18/4 (viernes 18 de abril)

Continuo con el modelaje del proyecto armado y con el aprendizaje de Blender

Avance hasta la fecha

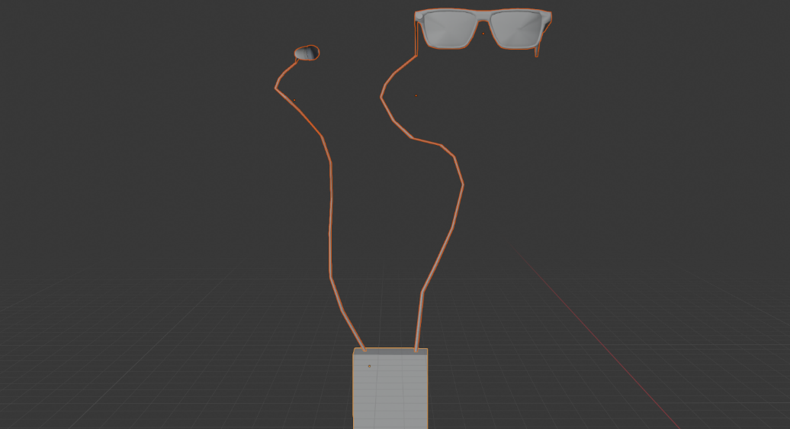
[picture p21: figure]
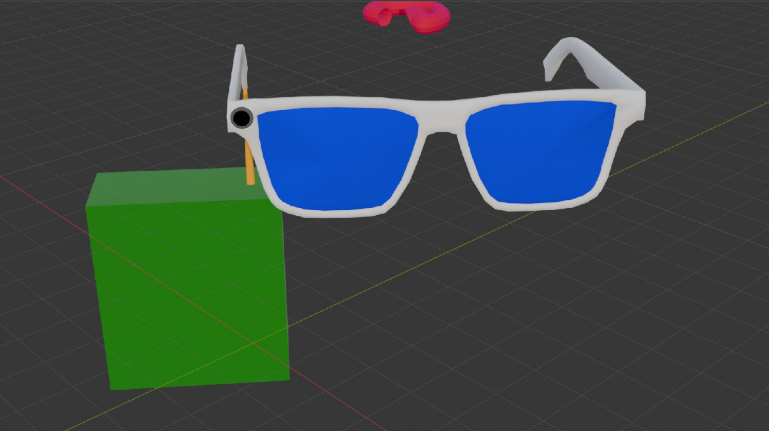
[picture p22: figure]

22/4 (martes 22 de abril)

Luego de definir nuestros puestos, me dedico a aprender como programar una pagina

23/4 (miércoles 23 de abril)

Comienzo con el aprendizaje y programación de la App. Primero, empezare programando una versión de página de la App para luego pasar a una App

29/4 (martes 29 de abril)

Continuo con el aprendizaje de programación

Configuro botones para que redirijan a Maps.

6/5 (martes 5 de mayo)

Continuo con el aprendizaje de programación

Consigo que la pagina pida el nombre y datos del acompañante o persona de confianza al que mandar la ubicación o datos de confianza

9/5 (viernes 9 de mayo)

Nos comunicamos con una organización de ayuda a la gente no vidente para acordar una reunión. Esto con el fin de obtener su apoyo.

14/5 (miércoles 14 de mayo)

Ayudo con el armado y ensayo de sensor de proximidad con circuito en Wokwi. Debido a problemas con la simulación, se tuvo que hacer la programación y simulación con Arduino.

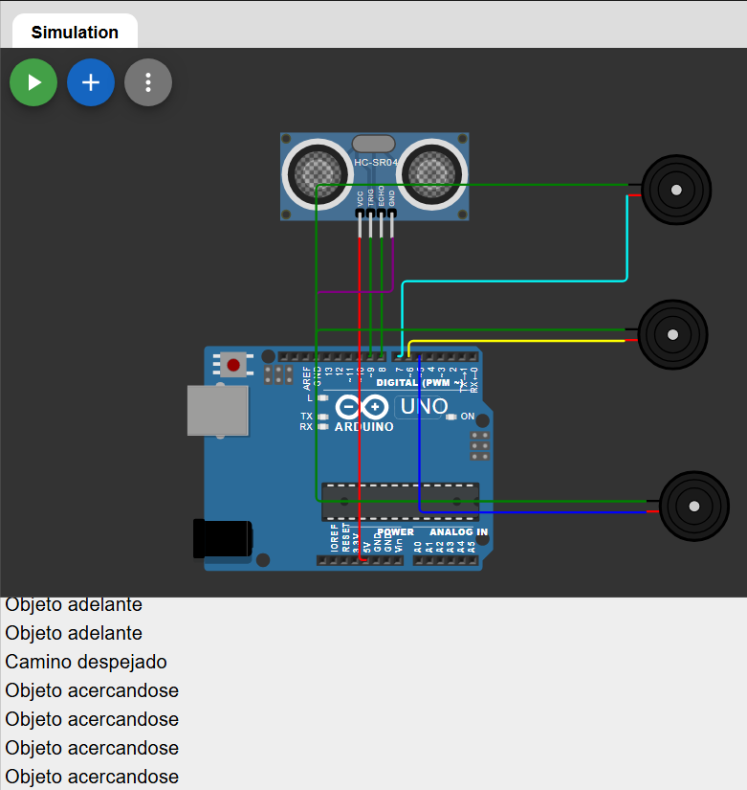
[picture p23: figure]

#define TRIG_PIN 9

#define ECHO_PIN 8

#define BUZZER_A 7

#define BUZZER_B 6

#define BUZZER_C 5

void setup() {

Serial.begin(9600);

pinMode(TRIG_PIN, OUTPUT);

pinMode(ECHO_PIN, INPUT);

pinMode(BUZZER_A, OUTPUT);

pinMode(BUZZER_B, OUTPUT);

pinMode(BUZZER_C, OUTPUT);

}

void loop() {

digitalWrite(TRIG_PIN, LOW);

delayMicroseconds(2);

digitalWrite(TRIG_PIN, HIGH);

delayMicroseconds(10);

digitalWrite(TRIG_PIN, LOW);

long duracion = pulseIn(ECHO_PIN, HIGH);

float distancia = duracion * 0.0343 / 2;

// Apaga todos los buzzers antes de activar el correcto

digitalWrite(BUZZER_A, LOW);

digitalWrite(BUZZER_B, LOW);

digitalWrite(BUZZER_C, LOW);

if (distancia <= 200) {

Serial.println("Objeto adelante");

digitalWrite(BUZZER_A, HIGH);

}

else if (distancia > 200 && distancia <= 350) {

Serial.println("Objeto acercándose");

digitalWrite(BUZZER_B, HIGH);

}

else {

Serial.println("Camino despejado");

digitalWrite(BUZZER_C, HIGH);

}

delay(1000);

}

30/5 (viernes 30 de mayo)

Realizamos una reunión con la directora de la organización ASAC, una organización que ayuda a la gente no vidente. La razón de la reunión fue la de recopilar y reunir información sobre algunos de los problemas que la gente no vidente debe afrontar en su día a día para poder implementarla en distintos aspectos de nuestro proyecto. Además, acordamos vernos de nuevo para que nos den su feedback de futuras actualizaciones o avances.


4/6 (miércoles 4 de junio)

Empiezo a aprender a programar una aplicación para el proyecto. La app tendrá todas las funciones que la pagina

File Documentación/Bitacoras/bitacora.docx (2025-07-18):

Ramirez Selene

Bitácora de proyecto

11/4 (viernes 11 de abril):

Inicio de la realización del código base en google colab de la red neuronal para que la inteligencia artificial (IA) identifique los objetos que se le asignan:

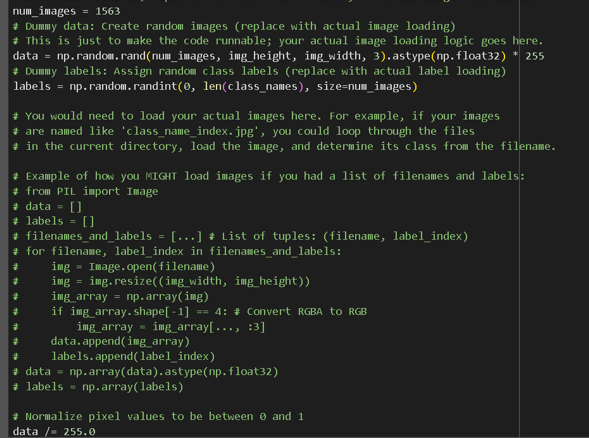
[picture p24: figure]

18/4 (viernes 18 de abril):

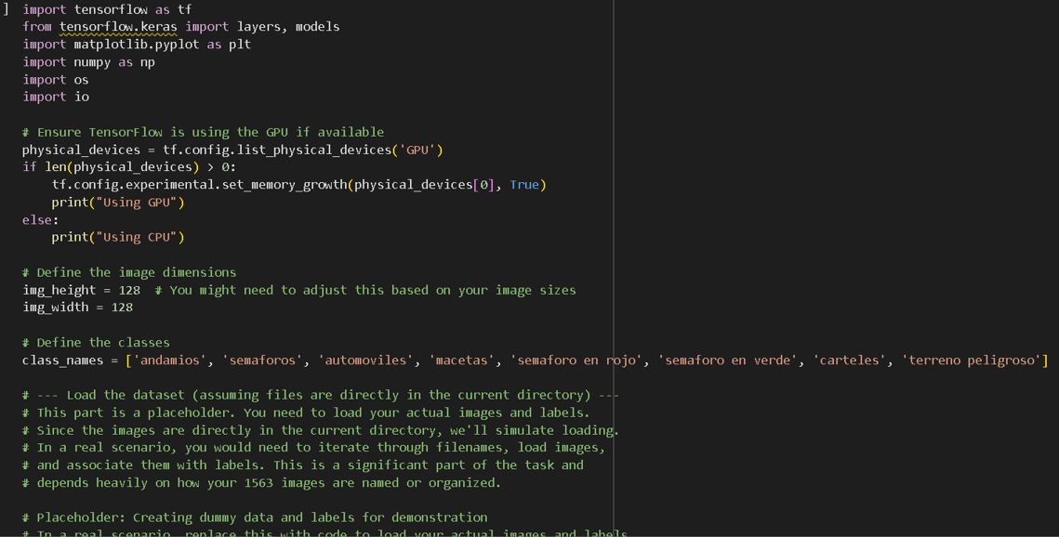
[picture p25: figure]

Continuación del código base de la red neuronal designando los objetos:

22/4 (martes 22 de abril):

Inicio del código base para la identificación de objetos en visual studio code con el lenguaje de Python:

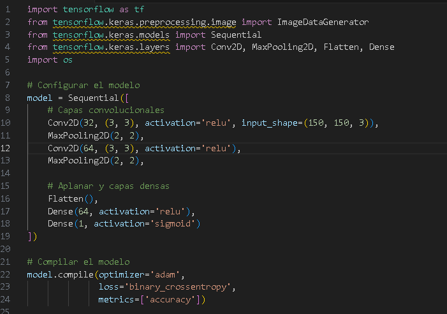
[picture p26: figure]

23/4 (miércoles 23 de abril):

Continuación del código en visual studio code:

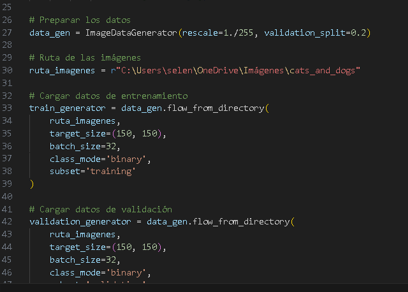
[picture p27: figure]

29/4 (martes 29 de abril):

Continuación del código base:

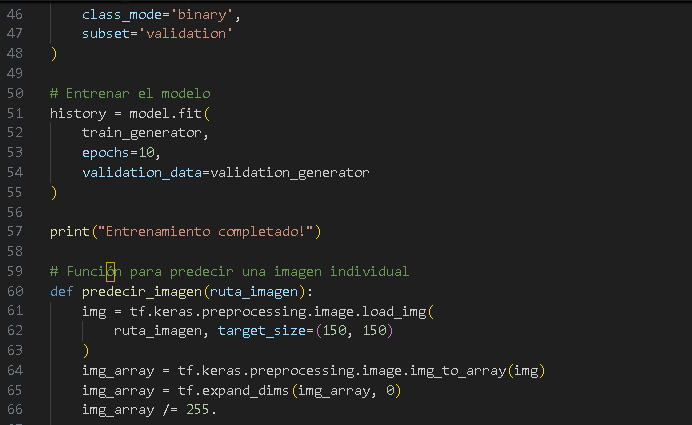
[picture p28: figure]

6/5 (martes 5 de mayo):
Seguimiento del código base:

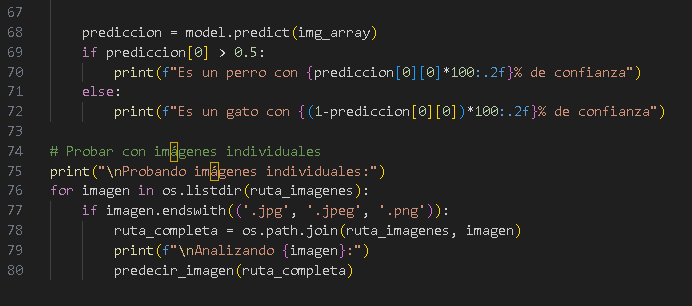
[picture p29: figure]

9/5 (viernes 9 de mayo):

Preparación de cosas para presentar al ASAC.

30/5 (viernes 30 de mayo):
Fuimos a una entrevista con la directora de la organización ASAC, una organización que ayuda a la gente no vidente. Con esa entrevista, reunimos información sobre algunos de los problemas que la gente no vidente debe afrontar en su día a día para poder implementarla en distintos aspectos de nuestro proyecto. Además, acordamos vernos de nuevo para que nos den su feedback de futuras actualizaciones o avances.


04/06 (viernes 04 de junio):
Busco referencias para hacer el circuito de audio:

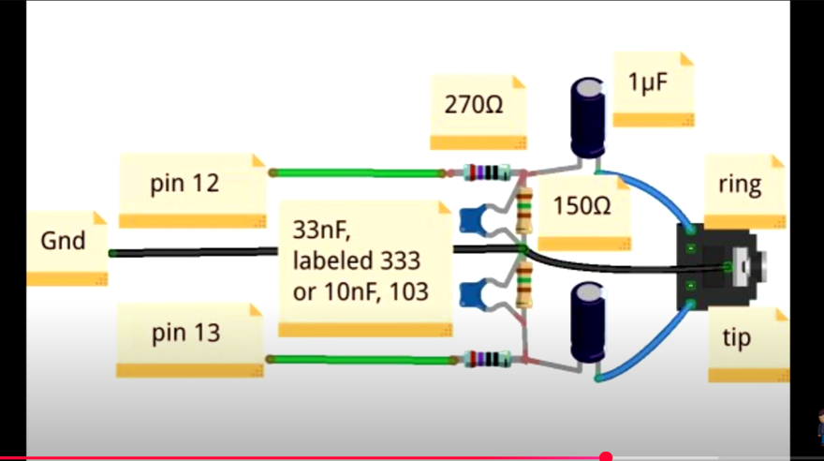
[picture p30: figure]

08/07(8 de julio):

Inicio del diseño diseño de circuito de audio mediante auriculares:

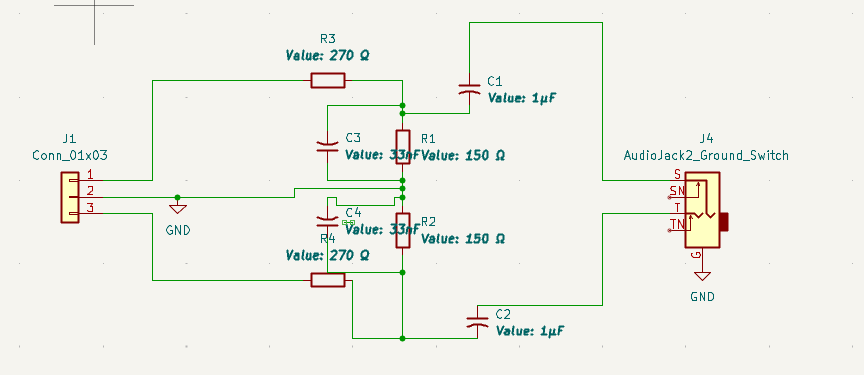
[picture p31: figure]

09/07 (miércoles 09 de julio):
Seguimiento del diseño del circuito de audio y finalización:

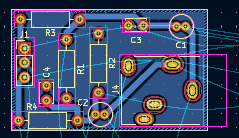
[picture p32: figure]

11/07(viernes11 de julio):
Impresión del circuito y planchado:

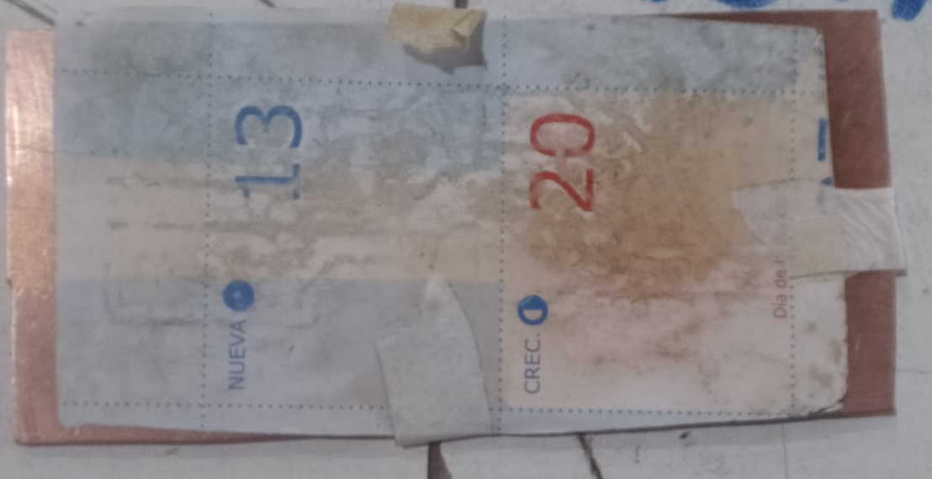
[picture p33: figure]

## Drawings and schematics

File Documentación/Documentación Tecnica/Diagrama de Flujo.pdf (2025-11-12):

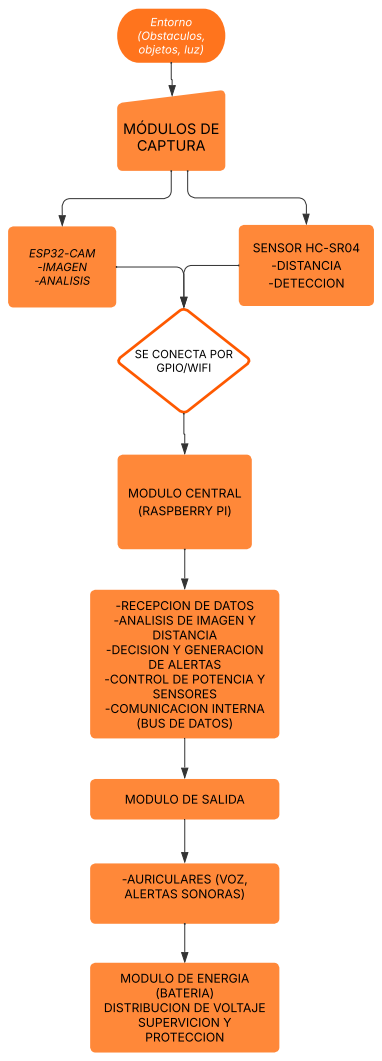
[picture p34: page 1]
Entorno (Obstaculos, objetos, luz); MÓDULOS DE CAPTURA; ESP32-CAM -IMAGEN -ANALISIS; SENSOR HC-SR04 -DISTANCIA -DETECCION; MODULO CENTRAL (RASPBERRY PI); -DECISION Y GENERACION DE ALERTAS; SENSORES; -AURICULARES (VOZ, ALERTAS SONORAS)

SE CONECTA POR
GPIO/WIFI

-RECEPCION DE DATOS
-ANALISIS DE IMAGEN Y
DISTANCIA

-CONTROL DE POTENCIA Y

-COMUNICACION INTERNA
(BUS DE DATOS)

MODULO DE SALIDA

MODULO DE ENERGIA
(BATERIA)

DISTRIBUCION DE VOLTAJE
SUPERVICION Y
PROTECCION

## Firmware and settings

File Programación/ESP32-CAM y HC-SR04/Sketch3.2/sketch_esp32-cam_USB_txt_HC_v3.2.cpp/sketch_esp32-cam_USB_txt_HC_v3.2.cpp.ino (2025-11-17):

#include "esp_camera.h"

// Pines AI-Thinker
#define PWDN_GPIO_NUM     32
#define RESET_GPIO_NUM    -1
#define XCLK_GPIO_NUM      0
#define SIOD_GPIO_NUM     26
#define SIOC_GPIO_NUM     27
#define Y9_GPIO_NUM       35
#define Y8_GPIO_NUM       34
#define Y7_GPIO_NUM       39
#define Y6_GPIO_NUM       36
#define Y5_GPIO_NUM       21
#define Y4_GPIO_NUM       19
#define Y3_GPIO_NUM       18
#define Y2_GPIO_NUM        5
#define VSYNC_GPIO_NUM    25
#define HREF_GPIO_NUM     23
#define PCLK_GPIO_NUM     22

// HC-SR04
#define TRIG_PIN 14
#define ECHO_PIN 15

#define BAUD_RATE 500000       // más estable en Raspberry Pi
#define CMD_TIMEOUT_MS 1000

void setup() {
  Serial.begin(BAUD_RATE);
  Serial.println("ESP32-CAM listo (optimizado para Raspberry Pi)");

  pinMode(TRIG_PIN, OUTPUT);
  pinMode(ECHO_PIN, INPUT);

  camera_config_t config;
  config.ledc_channel = LEDC_CHANNEL_0;
  config.ledc_timer = LEDC_TIMER_0;
  config.pin_d0 = Y2_GPIO_NUM;
  config.pin_d1 = Y3_GPIO_NUM;
  config.pin_d2 = Y4_GPIO_NUM;
  config.pin_d3 = Y5_GPIO_NUM;
  config.pin_d4 = Y6_GPIO_NUM;
  config.pin_d5 = Y7_GPIO_NUM;
  config.pin_d6 = Y8_GPIO_NUM;
  config.pin_d7 = Y9_GPIO_NUM;
  config.pin_xclk = XCLK_GPIO_NUM;
  config.pin_pclk = PCLK_GPIO_NUM;
  config.pin_vsync = VSYNC_GPIO_NUM;
  config.pin_href = HREF_GPIO_NUM;
  config.pin_sscb_sda = SIOD_GPIO_NUM;
  config.pin_sscb_scl = SIOC_GPIO_NUM;
  config.pin_pwdn = PWDN_GPIO_NUM;
  config.pin_reset = RESET_GPIO_NUM;
  config.xclk_freq_hz = 20000000;
  config.pixel_format = PIXFORMAT_JPEG;
  config.frame_size = FRAMESIZE_QVGA;  // 320x240
  config.jpeg_quality = 20;
  config.fb_count = 1;

  if (esp_camera_init(&config) != ESP_OK) {
    Serial.println("❌ Error al inicializar la cámara");
    while (true) delay(1000);
  }
  Serial.println("✅ Cámara inicializada correctamente");
}

float medirDistanciaCM() {
  digitalWrite(TRIG_PIN, LOW);
  delayMicroseconds(2);
  digitalWrite(TRIG_PIN, HIGH);
  delayMicroseconds(10);
  digitalWrite(TRIG_PIN, LOW);
  long duration = pulseIn(ECHO_PIN, HIGH, 30000);
  if (duration == 0) return -1.0;
  return (duration / 2.0) * 0.0343;
}

bool esperarComandoIMG(unsigned long timeout_ms) {
  unsigned long start = millis();
  String cmd = "";
  while (millis() - start < timeout_ms) {
    while (Serial.available()) {
      char c = (char)Serial.read();
      if (c == '\n') {
        cmd.trim();
        return (cmd == "IMG");
      }
      cmd += c;
    }
    delay(1);
  }
  return false;
}

void loop() {
  if (!esperarComandoIMG(CMD_TIMEOUT_MS)) {
    delay(10);
    return;
  }

  float distancia = medirDistanciaCM();
  if (distancia < 0) distancia = 0;

  camera_fb_t *fb = esp_camera_fb_get();
  if (!fb) {
    uint8_t zero[6] = {0};
    Serial.write(zero, 6);
    delay(30);
    return;
  }

  uint16_t dist_int = (uint16_t)distancia;
  uint8_t dist_bytes[2] = { (uint8_t)(dist_int >> 8), (uint8_t)dist_int };
  Serial.write(dist_bytes, 2);

  uint32_t len = fb->len;
  uint8_t header[4] = { (uint8_t)(len >> 24), (uint8_t)(len >> 16),
                        (uint8_t)(len >> 8), (uint8_t)len };
  Serial.write(header, 4);
  Serial.write(fb->buf, fb->len);
  Serial.flush();

  esp_camera_fb_return(fb);
  delay(30);
}

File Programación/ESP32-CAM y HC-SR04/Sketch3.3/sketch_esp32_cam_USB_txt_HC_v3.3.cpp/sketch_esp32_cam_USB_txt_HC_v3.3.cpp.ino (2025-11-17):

#include "esp_camera.h"

// --- Pines de la cámara (AI Thinker ESP32-CAM) ---
#define PWDN_GPIO_NUM     32
#define RESET_GPIO_NUM    -1
#define XCLK_GPIO_NUM      0
#define SIOD_GPIO_NUM     26
#define SIOC_GPIO_NUM     27

#define Y9_GPIO_NUM       35
#define Y8_GPIO_NUM       34
#define Y7_GPIO_NUM       39
#define Y6_GPIO_NUM       36
#define Y5_GPIO_NUM       21
#define Y4_GPIO_NUM       19
#define Y3_GPIO_NUM       18
#define Y2_GPIO_NUM        5
#define VSYNC_GPIO_NUM    25
#define HREF_GPIO_NUM     23
#define PCLK_GPIO_NUM     22

// --- Pines del sensor ultrasónico HC-SR04 ---
#define TRIG_PIN  14
#define ECHO_PIN  15

// --- Timeout para comandos ---
#define CMD_TIMEOUT_MS 1000

// =========================================================
// Configuración inicial
// =========================================================
void setup() {
  Serial.begin(500000);   // 🔹 BAUDRATE sincronizado con Raspberry Pi
  Serial.setTimeout(50);
  Serial.println("ESP32-CAM listo, esperando comando IMG...");

  // Pines HC-SR04
  pinMode(TRIG_PIN, OUTPUT);
  pinMode(ECHO_PIN, INPUT);

  // Configurar cámara
  camera_config_t config;
  config.ledc_channel = LEDC_CHANNEL_0;
  config.ledc_timer = LEDC_TIMER_0;
  config.pin_d0 = Y2_GPIO_NUM;
  config.pin_d1 = Y3_GPIO_NUM;
  config.pin_d2 = Y4_GPIO_NUM;
  config.pin_d3 = Y5_GPIO_NUM;
  config.pin_d4 = Y6_GPIO_NUM;
  config.pin_d5 = Y7_GPIO_NUM;
  config.pin_d6 = Y8_GPIO_NUM;
  config.pin_d7 = Y9_GPIO_NUM;
  config.pin_xclk = XCLK_GPIO_NUM;
  config.pin_pclk = PCLK_GPIO_NUM;
  config.pin_vsync = VSYNC_GPIO_NUM;
  config.pin_href = HREF_GPIO_NUM;
  config.pin_sscb_sda = SIOD_GPIO_NUM;
  config.pin_sscb_scl = SIOC_GPIO_NUM;
  config.pin_pwdn = PWDN_GPIO_NUM;
  config.pin_reset = RESET_GPIO_NUM;
  config.xclk_freq_hz = 20000000;
  config.pixel_format = PIXFORMAT_JPEG;
  config.frame_size = FRAMESIZE_VGA;  // 640x480
  config.jpeg_quality = 12;           // menor = mejor calidad
  config.fb_count = 1;

  if (esp_camera_init(&config) != ESP_OK) {
    Serial.println("❌ Error al inicializar la cámara");
    while (true) delay(1000);
  }

  Serial.println("✅ Cámara inicializada correctamente");
}

// =========================================================
// Función para medir distancia con HC-SR04
// =========================================================
float medirDistanciaCM() {
  digitalWrite(TRIG_PIN, LOW);
  delayMicroseconds(2);
  digitalWrite(TRIG_PIN, HIGH);
  delayMicroseconds(10);
  digitalWrite(TRIG_PIN, LOW);

  long duracion = pulseIn(ECHO_PIN, HIGH, 30000);  // 30ms = ~5m máx
  if (duracion == 0) return -1.0;
  return (duracion / 2.0) * 0.0343;
}

// =========================================================
// Esperar comando IMG
// =========================================================
bool esperarComandoIMG(unsigned long timeout_ms) {
  unsigned long start = millis();
  String cmd = "";
  while (millis() - start < timeout_ms) {
    while (Serial.available() > 0) {
      char c = (char)Serial.read();
      if (c == '\n') {
        cmd.trim();
        return (cmd == "IMG");
      } else {
        cmd += c;
      }
    }
    delay(1);
  }
  return false;
}

// =========================================================
// LOOP PRINCIPAL
// =========================================================
void loop() {
  // Esperar comando desde Raspberry Pi
  if (!esperarComandoIMG(CMD_TIMEOUT_MS)) {
    delay(10);
    return;
  }

  // Medir distancia
  float dist = medirDistanciaCM();
  if (dist < 0) dist = 0;
  uint16_t dist_int = (uint16_t)dist;

  // Capturar imagen
  camera_fb_t *fb = esp_camera_fb_get();
  if (!fb) {
    Serial.println("⚠️ Error capturando imagen");
    return;
  }

  // --- PROTOCOLO DE ENVÍO ---
  // 1️⃣ Cabecera fija
  Serial.write("IMGSTART", 8);

  // 2️⃣ Distancia (2 bytes big-endian)
  uint8_t dist_bytes[2];
  dist_bytes[0] = (dist_int >> 8) & 0xFF;
  dist_bytes[1] = dist_int & 0xFF;
  Serial.write(dist_bytes, 2);

  // 3️⃣ Tamaño de imagen (4 bytes big-endian)
  uint32_t len = fb->len;
  uint8_t len_bytes[4];
  len_bytes[0] = (len >> 24) & 0xFF;
  len_bytes[1] = (len >> 16) & 0xFF;
  len_bytes[2] = (len >> 8) & 0xFF;
  len_bytes[3] = len & 0xFF;
  Serial.write(len_bytes, 4);

  // 4️⃣ Imagen JPEG
  Serial.write(fb->buf, fb->len);
  Serial.flush();

  esp_camera_fb_return(fb);
  delay(50);  // evita saturar el bus
}

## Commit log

2025-07-19 bitacora
    a pesar de mis intentos, no pude accesar al repositorio, aparece que no tengo acceso al repositorio, así que lo subo desde la cuenta de mi compañero
2025-09-16 Subo la pagina a Github
    La pagina de apoyo ya cuenta con varios avances, siendo estos: Coneccion con el usuario y la persona designada a traves de el mail personal, aviso por mail de confirmacion y de ubicacion, y lectura d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
2025-10-21 Mejora al sistema de ubicación personal
    Hago que la pagina diga los locales cercanos para ubicar al usuario en vez de dar las coordenadas exactas. Pero, si no hay locales en un radio de 10 metros, si dira las coordenadas exacta (Se cambiar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
2025-11-07 diseño principal de anteojos
    diseño como prototipo principal
    [lentes.dwg]
2025-11-07 Acomodo y organizo.
    Creo carpeta de documentacion. Muevo las bitacoras ahi y subo la Carpeta Tecnica
2025-11-12 Subo varias cosas
    Subo el manual de usuario y el codigo de Latex. Subo el codigo usado en la raspberry y en la ESP32-CAM. Subo el diagrama de flujo y de solución
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2025-11-12 Creo carpeta de Lentes
    Subo todo lo relacionado con los lentes que tengamos a la carpeta
    [lentes.dwg]
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2025-11-13 Creo Subcarpeta de Proceso en Imagenes
    Creo carpeta y subo primera imagen
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2025-11-17 Actualizo README
    Le doy mas estilo y color al README, ademas de darle mas informacion
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2025-11-17 lista
    subo la lista de compras
    [Compras VIA.xlsx]
2025-11-17 subo los archivos main de deteccion de objetos
    [pyvenv.cfg]
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2025-11-17 primer diseño de lentes
    creo primer diseño de lentes como la idea principal
    [primer diseño e idea de lentes.dwg]
2025-11-17 segundo diseño de lentes
    creo segundo diseño de lentes
    [segundo diseño de lentes.dwg]
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2025-11-17 tercer diseñoo de lentes
    creo tercer modelo de lentes
    [tercer diseño de lentes.dwg]
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2025-11-17 (me olvide de esto)
    [pyvenv.cfg]
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2025-11-17 quiento diseño de lentes
    armo primero diseño con agujeros en los lentes
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2025-11-17 componentes
    todo esto incluye la compra de capacitores, resistencias, jack de audio
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2025-11-17 sensor de proximidad
    este sensor es comprado por nuestra parte, debido a que la segunda compra nunca se nos proveyó
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2025-11-17 esp32 cam
    esta es una ESP32-CAM con su camara
    compramos 2 y luego se quemaron
    pedimos otro y nunca se nos proveyó
2025-11-17 termocontraíble
    este es el termocontraíble que pedimos, como nunca fue comprado tuvimos que pedir al pañol
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2025-11-17 algunos main de deteccion de objetos
    [pyvenv.cfg]
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2025-11-17 sexto diseño de lentes
    diseño lentes con agujeros por donde los cables entran dpor la punta de las patillas y salen de frente
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2025-11-18 Archivo 3d
    Este es el archivo 3D de los lentes realizado por mi
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2025-11-18 Contacto
    Este es el codigo del apartado de contacto en la pagina
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2025-11-18 Producto
    Este es el codigo del apartado de producto en la pagina
2025-11-18 final
    completo el código y analizo si todo funciona con un print final de confirmación
2025-11-18 armo carpeta de circuito de audio
    armo carpeta de documentación de progreso de circuito de audio
2025-11-18 diseño de circuito de audio
    realizoo el diseño del circuitoo de audio para auriculares de cable
2025-11-18 ubicacion de componentes
    posiciono los componentes en un orden que no intervenga
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2025-11-18 commit V4 de detección de yolov
    basicamente el codigo para que la raspberry detecte las cosas pero mejorada
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2025-11-18 Prueba de la camara
    Probando la camara conectada a la raspberry en la protoboard
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2025-11-18 Sensor en la protoboard
    Prueba del sensor de proximidad en una protoboard
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2025-11-18 carpeta de aplicación de GPS
    creo carpeta de desarrollo de aplicación GPS
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2025-11-18 segunda parte de primer codigo
    sigo con el primer código de prueba para el sistema de GPS
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2025-11-18 Apartado de contacto
    El apartado de contacto finalizado y conectado directamente a nuestro mail
2025-11-18 Modelo 3d
    Modelo 3D insertado en la pagina con los detalles de funcionamiento a su derecha
2025-11-18 tercera parte de código principal
    termino con el primer código de prueba
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2025-11-18 Borro lo que creo causa el problema
2025-11-18 Pruebo intento de arreglo
2025-11-19 código final parte 2
    continuo con el código final del la aplicación
2025-11-19 Varios cambios
    Borro archivo inutil usado para probar error de github. Cambio ligeramente los nombre de algunas carpetas
    [primer diseño e idea de lentes.dwg, segundo diseño de lentes.dwg, tercer diseño de lentes.dwg]
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2025-11-26 Foto grupas de la expo
    Foto grupal del día de la exposición
2025-11-26 Notas de la 2da visita a la ASAC
    Son las notas de lo q nos propuso el profesor de la ASAC, para mejorar
2025-11-26 Video de Presentación 1ra parte
    Este es el video de Presentación de V.I.A 1ra parte
2025-11-26 Video de presentación 2da parte
    Aca esta la 2da parte del video
2025-11-28 Subo temas de la presentación
    Subo Presentación y GIF del modelo de los lentes
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2025-12-01 añado a la lista los auriculares oseos
    en este archivo mando todas las compras actualizadas junto con los auriculares
    [Compras VIA.xlsx]
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2025-12-08 testeo de los lentes (video)
    aqui tarde en hacerlo porque aparte de ciertos problemas con la camara, yo me estaba mudando por lo que no tuve mucho tiempo para hacer algunas cosas en mente.
    los auriculares son muy comodos y la verdad no fue dificil configurarlos, tan solo necesité de mi celular (cualquier dispositivo tambien sirve) y ver cual sea lo mas comodo para la persona en cuanto como subir/bajar volumen y encendido
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2025-12-18 Compras actualizadas
    [Compras%20VIA.xlsx]
